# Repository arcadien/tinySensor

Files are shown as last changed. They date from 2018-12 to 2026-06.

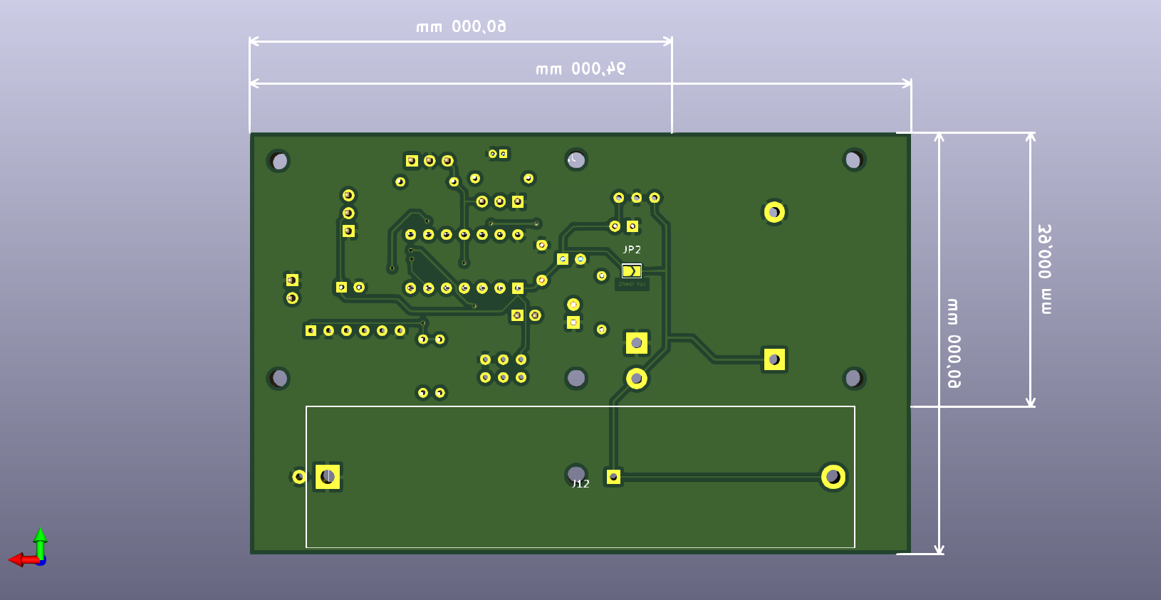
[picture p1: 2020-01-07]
doc/boardv2_copper.png

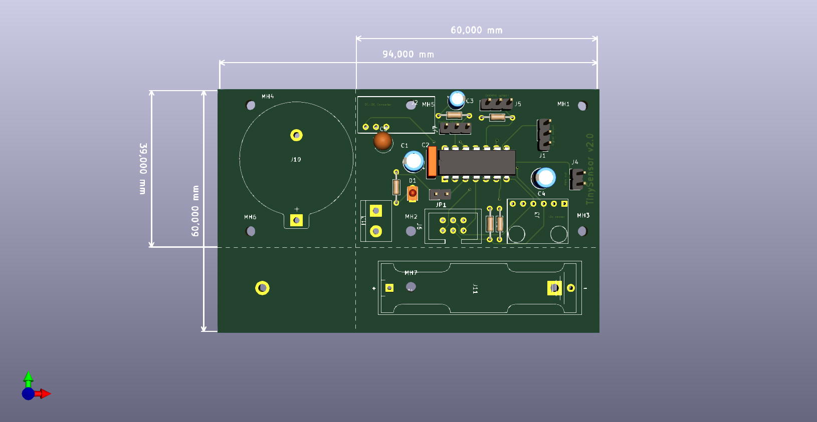
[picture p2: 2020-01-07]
doc/boardv2.png

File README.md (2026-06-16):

# TinySensor 



TinySensor aims to provide a customisable firmware and a hardware design for low-power environment sensors using wireless communication.

In the complete system, data is processed by a [Domoticz](https://domoticz.com/)/[RFlink](http://www.rflink.nl/blog2/) couple.
Data decoding is also tested using [RTL_433](https://github.com/merbanan/rtl_433) decoder.
Large part of the code, especially wireless encoders, are unit-tested.

## Supported MCUs
* ATTiny84a
* ATMega328p (ongoing)

## Supported sensors
* I2C sensors (eg. [Bosch BME/BMP280](https://www.bosch-sensortec.com/bst/products/all_products/bme280))
* Analog sensors (eg. [LM35](http://www.ti.com/lit/ds/symlink/lm35.pdf))
* OneWire sensors (eg. [Dallas DS18S20](https://datasheets.maximintegrated.com/en/ds/DS18S20.pdf))

## Wireless technology
* "one pin" emmiters. Tested with low-cost 433Mhz emmitters.

## Wireless protocol
* Oregon(c) for environment measurement transmission
* X10(c) for (optional) battery level transmission
* Lacrosse Technology for enviroment measurement transmission

## Used libraries
Various libraries are used here, and some where tweaked to remove any Arduino dependencies, making the whole firmware more compact:
* Sparkfun [BME280 sensor library](https://github.com/sparkfun/SparkFun_BME280_Arduino_Library) with all SPI related code removed
* [Tiny I2C](https://github.com/arcadien/tiny-i2c.git) of [David Johnson-Davies](https://github.com/technoblogy)
* [Unity test harness](http://www.throwtheswitch.org/unity) from Throw The Switch, for all testing code
* DS18B20 library of [Jacek Wieczorek](https://github.com/Jacajack/avr-ds18b20)

## Firmware builder
A web application wrapped in a Docker container allow to build the firmware in a sealed environment. NOTE: It is at his early stage!

## Useful documentation about low power AVR
* [AVR4013: picoPower Basics](http://www.microchip.com/downloads/en/AppNotes/doc8349.pdf)

## Development

TinySensor build environment now uses [PlatformIO](https://platformio.org/).

## Hardware options

TinySensor can use combination of sensors, the limit comes from amount of flash memory on the ATTiny.

### DS18B20

OneWire sensor, cheap and efficient.

### BMP/BME 280 environment sensor
The [BMP280](https://www.bosch-sensortec.com/products/environmental-sensors/pressure-sensors/pressure-sensors-bmp280-1.html) and the [BME280](https://www.bosch-sensortec.com/products/environmental-sensors/humidity-sensors-bme280/) share the same library, but the BME provide humidity sensing, and thus use more memory.

### Analog sensor

Analog sensor can be used for [LM35](https://www.ti.com/lit/ds/symlink/lm35.pdf) temperature sensor, or [LDR](https://en.wikipedia.org/wiki/Photoresistor).

### LM35 temperature sensor

#### Without negative temperature support
A 0v ground reference is needed.
Solder pads *2* and *3* of **J4**, (rear side) as well **JP3**. 

#### With negative temperature support
In the case of a *-CAZ* version, temperature below 0 can be measured. 
To allow this, two 1N914 diodes must be placed to put the sensor reference below 0v. This setup is documented in the LM35 datasheet.
On TinySensor board v2.1 and up, this can be implemented by:
* solding **D2** and **D3** diodes
*solding **R4** with a value of 18k
* solding **JP3** to bypass C3 capacitor
* solding pads *1* and *2* of **J4** (rear side) to set ground reference.

#### Notes about swing

You can add a filter capacitor *C3* to avoid swing if the wire is long. In this case, do not solder *JP3*.
See datasheet for details.

# LDR
Use the right value for **R4** (should match the used LDR) and solder **JP3** and, on **JP4**, middle and *3* pads. This way, there will be no RC filter (no cap because of **J3**) and Vss analog reference thanks of **JP4**.

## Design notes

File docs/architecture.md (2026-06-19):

# Architecture

_Last updated: 2026-06-19 — requirements: TECH-SENSOR-001_

## Component Diagram

```mermaid
graph TD
  main["main.cpp (loop)"] -->|Hal*| HAL
  main -->|Hal*| OregonV3
  main -->|Hal*| LacrosseWS7000
  main -->|Hal*| x10rf
  main -->|Hal*| BMx280
  main -->|Hal*| SoftSerial
  main -->|Hal*| Ds18b20["Ds18b20 (1-Wire wrapper)"]
  Ds18b20 -->|"1-Wire PA3"| ds18b20["ds18b20 (1-Wire driver library)"]
  main -->|"I2C 0x23"| BH1750["BH1750 (I2C light sensor)"]

  HAL["Hal (interface)"] --> Attiny84aHal["Attiny84aHal (AVR)"]
  HAL --> TestHal["TestHal_ (host/test)"]

  OregonV3 -->|RadioGoHigh/Low\nDelay512Us/1024Us| HAL
  LacrosseWS7000 -->|RadioGoHigh/Low\nDelay400Us| HAL
  x10rf -->|"RadioGoHigh/Low\nDelayX10PreambleHigh/Low\nDelayX10BitShort/Long\nDelayX10Gap"| HAL
  SoftSerial -->|SerialGoHigh/Low| HAL
  BMx280 -->|I2C via TinyI2C| HAL
  Ds18b20 -->|Delay1s| HAL
```

## Component Responsibilities

| Component | Responsibility | Requirement(s) |
|---|---|---|
| `Hal` | Pure-virtual interface isolating all hardware I/O | — |
| `Attiny84aHal` | ATtiny84a production implementation of Hal | — |
| `TestHal_` | Host-native stub; records HAL calls as char tokens in `Orders` vector | — |
| `OregonV3` | Encodes temperature/humidity/pressure into Oregon Scientific v3 frames | — |
| `LacrosseWS7000` | Encodes temperature/humidity/pressure/luminosity into Lacrosse WS7000 frames | — |
| `x10rf` | Encodes meter readings into X10 RF frames (battery voltage, analog sensors); routes all timing through Hal X10 delay methods | TECH-X10-001, TECH-X10-002 |
| `BMx280` | Abstracts BMP280/BME280 I2C sensor behind a common interface | — |
| `Ds18b20` | Wrapper class encapsulating DS18B20 1-Wire access; accepts `Hal*` at construction; exposes `Begin()`, `Convert()`, `Read()`; uses `hal->Delay1s()` between convert and read on AVR; stubs on non-AVR | TECH-SENSOR-001 |
| `SoftSerial` | Software UART for debug logging (optional, `USE_SERIAL_LOG`) | — |
| `ds18b20` | 1-Wire driver library on PA3; called only through `Ds18b20` wrapper | FUNC-SENSOR-002 |
| `BH1750` | I2C light sensor at 0x23; ONE_TIME_HIGH_RES_MODE; result in lux | FUNC-SENSOR-003 |
| `main.cpp` | Measurement loop: power on → read sensors → encode → transmit → hibernate | — |
| `AnalogFilter` | Accumulates ADC samples with configurable warm-up exclusion; returns integer floor mean | TECH-FILTER-001, TECH-FILTER-002 |
| `ConversionTools` | BCD-in-hex conversion utilities for 16-bit and 32-bit decimal values | TECH-CONVERT-001, TECH-CONVERT-002 |

## Dependency Injection Map

| Component | Receives | Via |
|---|---|-----|
| `OregonV3` | `Hal*` | constructor |
| `LacrosseWS7000` | `Hal*` | constructor |
| `x10rf` | `Hal*` | constructor |
| `BMx280` | `Hal*` | constructor |
| `Ds18b20` | `Hal*` | constructor |
| `SoftSerial` | `Hal*` | constructor |

All protocol encoders and sensor wrappers receive `Hal*` at construction. They must never access AVR registers directly.

## Build-time Configuration

Every physical board is a separate PlatformIO environment with its own `build_flags`. There is no runtime configuration. See `docs/environments.md` for the full table.

## Requirement → Component Traceability

| Requirement | Component(s) | Notes |
|---|---|---|
| FUNC-OREGON-001 | `OregonV3` | Zero bit HAL call sequence (H-D512-L-D1024-H-D512) |
| FUNC-OREGON-002 | `OregonV3` | One bit HAL call sequence (L-D512-H-D1024-L-D512) |
| FUNC-OREGON-003 | `OregonV3` | Byte serialisation: LSB nibble before MSB nibble |
| FUNC-OREGON-004 | `OregonV3` | Frame structure: 3-byte preamble + payload + 1-byte postamble |
| FUNC-OREGON-005 | `OregonV3` | Positive temperature encoding in bytes 4–5 |
| FUNC-OREGON-006 | `OregonV3` | Negative temperature sign flag in byte 5 |
| FUNC-OREGON-007 | `OregonV3` | Humidity encoding with swapped nibbles in byte 6 |
| FUNC-OREGON-008 | `OregonV3` | Pressure encoding with 795 hPa offset; weather prediction in byte 9 |
| FUNC-OREGON-009 | `OregonV3` | Channel 1–3 encoded as bitmask in byte 2; out-of-range ignored |
| FUNC-OREGON-010 | `OregonV3` | Rolling code stored in low nibble of byte 2 and high nibble of byte 3 |
| FUNC-OREGON-011 | `OregonV3` | Battery-low flag is bit 2 of byte 3 |
| FUNC-OREGON-012 | `OregonV3` | Device ID auto-selected by FinalizeMessage() based on messageStatus |
| FUNC-OREGON-013 | `OregonV3` | messageStatus bit-field (bit0=temp, bit1=humi, bit2=press) |
| FUNC-OREGON-014 | `OregonV3` | Full frame matches Oregon Scientific v3 reference decoding samples |
| FUNC-LACROSSE-001 | `LacrosseWS7000` | Preamble is exactly 10 consecutive zero bits |
| FUNC-LACROSSE-002 | `LacrosseWS7000` | Sensor-type nibble encoding: 0=temp, 1=T+H, 4=T+H+P, 5=lux, F=unknown |
| FUNC-LACROSSE-003 | `LacrosseWS7000` | Address (0–7) in bits 0–2; negative temperature sign in bit 3 of second nibble |
| FUNC-LACROSSE-004 | `LacrosseWS7000` | Temperature clamped ±99 °C; encoded as decimal/unit/dozen nibbles |
| FUNC-LACROSSE-005 | `LacrosseWS7000` | Humidity clamped to 99.9 %; encoded as decimal/unit/dozen nibbles |
| FUNC-LACROSSE-006 | `LacrosseWS7000` | Pressure clamped 850–1100 hPa, offset −200; encoded as four nibbles |
| FUNC-LACROSSE-007 | `LacrosseWS7000` | Luminosity encoded as 7 nibbles in type-5 (light sensor) frame |
| FUNC-LACROSSE-008 | `LacrosseWS7000` | Frame ends with XOR checksum nibble and running-sum nibble (init 5) |
| FUNC-LACROSSE-009 | `LacrosseWS7000` | Each nibble followed by mandatory trailing one-bit separator |
| FUNC-X10-001 | `x10rf` | RFXmeter 6-byte frame: address, partial complement, 24-bit value, packet-type nibble, nibble-sum parity |
| FUNC-X10-002 | `x10rf` | RFXsensor 4-byte frame: address+type bits, partial complement, value, packet-type status + nibble-sum parity |
| FUNC-X10-003 | `x10rf` | x10Switch 4-byte frame: house-code nibble lookup, bit-scattered unit code, full-byte complements |
| FUNC-X10-004 | `x10rf` | x10Security 6-byte frame: address, swapped-nibble complement, command + complement, id, XOR-fold parity |
| FUNC-X10-005 | `x10rf` | Transmission repeated rf_repeats times with 40 ms inter-repeat cooldown via DelayX10Gap (see TECH-X10-001) |
| FUNC-X10-006 | `main.cpp` | Battery voltage BCD-encoded and transmitted via RFXmeter; suppressed when lowBattery |
| FUNC-X10-007 | `main.cpp` | Analog sensor voltage BCD-encoded and transmitted via RFXmeter; suppressed when lowBattery |
| TECH-HAL-001 | `Hal` / `Attiny84aHal` / `TestHal_` | Encoders and wrappers take Hal* at construction; no direct AVR register access |
| TECH-HAL-002 | `TestHal_` | Orders vector char-token recording: H, L, D, P, A, S, W |
| TECH-HAL-003 | `Hal` | ComputeVccMv and ConvertAnalogValueToMv are non-virtual concrete methods on Hal base |
| TECH-HAL-004 | `Attiny84aHal` | Constructor power-reduction: disables Timer1, ADC, analog comparator; pull-ups unused pins; BOD-sleep disable |
| TECH-HAL-005 | `Attiny84aHal` / `TestHal_` | LedOn/LedOff toggle PORTB PB1 on AVR; toggle IsLedOn in TestHal_ |
| TECH-HAL-006 | `Attiny84aHal` / `TestHal_` | Init() calls TinyI2C.init() on AVR (USE_I2C); sets I2CIsConfigured in TestHal_ |
| TECH-FILTER-001 | `AnalogFilter` | Discards first `exclusion` values; accumulates up to `samples`; Get() returns integer floor mean |
| TECH-FILTER-002 | `AnalogFilter` | Push() after samples count reached is silently ignored; Get() returns mean of first samples values |
| TECH-CONVERT-001 | `ConversionTools` | dec16ToHex packs each decimal digit of uint16_t into one nibble (BCD-in-hex) |
| TECH-CONVERT-002 | `ConversionTools` | dec32ToHex packs each decimal digit of uint32_t into one nibble (BCD-in-hex) |
| TECH-SERIAL-001 | `SoftSerial` | Output-only UART at 9600 baud; bit period = (1 000 000 / 9600) − 25 µs; driven by SerialGoHigh/Low |
| TECH-SERIAL-002 | `main.cpp` | SoftSerial instantiated and SerialPrintInfo active only when USE_SERIAL_LOG defined; otherwise no-op |
| TECH-X10-001 | `Hal` / `Attiny84aHal` / `TestHal_` | Five new pure-virtual Hal methods: DelayX10PreambleHigh (8960 µs), DelayX10PreambleLow (4500 µs), DelayX10BitShort (560 µs), DelayX10BitLong (1120 µs), DelayX10Gap (40000 µs) |
| TECH-X10-002 | `x10rf` | x10rf replaces all file-static _delay_us() calls with the five new Hal timing methods; <util/delay.h> block removed |
| FUNC-BATTERY-001 | `Hal` / `main.cpp` | ComputeVccMv reads internal 1.1 V ADC ref; calibrated constant supplied as INTERNAL_1v1 build flag |
| FUNC-BATTERY-002 | `Hal` / `main.cpp` | batteryVoltageInMv = vccMv (BATTERY_IS_VCC) or ConvertAnalogValueToMv(GetRawBattery(), vccMv) |
| FUNC-BATTERY-003 | `main.cpp` | lowBattery flag gates Oregon SetBatteryLow and suppresses all RFXmeter transmissions |
| FUNC-SENSOR-001 | `BMx280` | Wraps BMP280/BME280 at I2C 0x76; Begin/GetTemperature/GetPressure/GetHumidity/Shutdown interface |
| FUNC-SENSOR-002 | `Ds18b20` | ds18b20convert + ds18b20read on PA3; raw / 16 = temperature in °C; accessed only through Ds18b20 wrapper |
| TECH-SENSOR-001 | `Ds18b20` | DS18B20 access encapsulated in Ds18b20 wrapper; main.cpp must not reference PORTA/DDRA/PINA or ds18b20 library functions directly |
| FUNC-SENSOR-003 | `main.cpp` (BH1750) / `LacrosseWS7000` | BH1750 at I2C 0x23 ONE_TIME_HIGH_RES_MODE; lux reported as two Lacrosse type-5 frames |
| FUNC-ANALOG-001 | `Hal` / `main.cpp` | GetRawAnalogSensor() reads PA0; ConvertAnalogValueToMv converts to mV using vccMv from FUNC-BATTERY-001 |
| CONF-BUILD-001 | `main.cpp` / `platformio.ini` | Exactly one of USE_OREGON or USE_LACROSSE per environment; violated at compile time otherwise |
| CONF-BUILD-002 | `main.cpp` / `include/config.h` | Sensor type flag (USE_BMP280/BME280/DS18B20/BH1750) selects included driver; USE_I2C auto-derived |
| CONF-BUILD-003 | `main.cpp` / `platformio.ini` | OREGON_CHANNEL (1–3) and OREGON_RCODE (≤ 0xA5) applied to OregonV3 in main() |
| CONF-BUILD-004 | `main.cpp` / `platformio.ini` | LACROSSE_ID enum value applied to LacrosseWS7000 in main() |
| CONF-BUILD-005 | `Hal` / `platformio.ini` | INTERNAL_1v1 (mV) chip-calibrated constant consumed by Hal::ComputeVccMv() |
| CONF-BUILD-006 | `main.cpp` / `include/config.h` | SLEEP_TIME_IN_SECONDS passed to Hal::Hibernate(); default 32 s from config.h |
| CONF-BUILD-007 | `main.cpp` / `include/config.h` | LOW_BATTERY_VOLTAGE compared against batteryVoltageInMv; default 2000 mV from config.h |
| CONF-BUILD-008 | `main.cpp` / `platformio.ini` | BATTERY_VOLTAGE_X10_ID passed as address to x10rf::RFXmeter() for battery reporting |
| CONF-BUILD-009 | `main.cpp` / `platformio.ini` | ANALOG1_X10_ID optionally enables PA0 analog transmission via x10rf::RFXmeter() |
| CONF-BUILD-010 | `main.cpp` / `platformio.ini` | BATTERY_IS_VCC skips GetRawBattery(); batteryVoltageInMv = vccMv directly |
| CONF-BUILD-011 | `platformio.ini` | USE_CHARGE_PUMP is an informational flag only; no firmware branch depends on it |
| PLAT-POWER-001 | `Attiny84aHal` | Hibernate loops SLEEP_MODE_PWR_DOWN for ceil(s/8) WDT periods; minimum 1 period |
| PLAT-POWER-002 | `Attiny84aHal` / `main.cpp` | PA2 (SENSOR_VCC) driven high before first sensor read; driven low after last transmission |
| PLAT-POWER-003 | `Attiny84aHal` | PRR bits for USI/Timer0/Timer1/ADC set in sleep(); GPIO reconfigured as inputs with pull-ups; all restored on wake |
| PLAT-POWER-004 | `main.cpp` | TRANSMIT_WITH_LED macro wraps every Send(): LedOn() before, LedOff() + Delay30ms() after |
| PLAT-POWER-005 | `Attiny84aHal` / `platformio.ini` | ATtiny84a at F_CPU = 1 000 000 L; all HAL delay methods calibrated to this frequency |

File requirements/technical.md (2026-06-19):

# Technical Requirements

<!-- Requirements are added here during Phase 2 of the RBD workflow. -->
<!-- Format: req(ID): title -->

### TECH-HAL-001
**Title:** All encoders and sensor wrappers receive Hal* at construction and never access AVR registers directly
**Status:** validated
**Dependencies:** —
**Description:** Every protocol encoder (`OregonV3`, `LacrosseWS7000`, `x10rf`, `SoftSerial`) and sensor wrapper (`BMx280`) must accept a `Hal*` parameter at construction time and must call only `Hal` virtual methods for all hardware I/O. Direct access to AVR registers (`PORTA`, `PORTB`, `ADCSRA`, etc.) is forbidden outside `Attiny84aHal`.

---

### TECH-HAL-002
**Title:** TestHal_ records each HAL call as a single-character token in the Orders vector
**Status:** validated
**Dependencies:** TECH-HAL-001
**Description:** `TestHal_` appends one character per call to its `Orders` vector: `H`=`RadioGoHigh`, `L`=`RadioGoLow`, `D`=`Delay512Us`, `P`=`Delay1024Us`, `A`=`Delay400Us`, `S`=`SerialGoHigh`, `W`=`SerialGoLow`. Protocol tests verify correctness by asserting against expected `Orders` sequences.

---

### TECH-HAL-003
**Title:** ComputeVccMv and ConvertAnalogValueToMv are non-virtual concrete methods on the Hal base class
**Status:** validated
**Dependencies:** —
**Description:** `Hal::ComputeVccMv(uint16_t known11refValue)` and `Hal::ConvertAnalogValueToMv(uint16_t adcReading, uint16_t vccInMv)` are implemented directly on `Hal` and are not overridden by any subclass. Both `Attiny84aHal` and `TestHal_` inherit them unchanged.

---

### TECH-HAL-004
**Title:** Attiny84aHal constructor disables Timer1, ADC, and analog comparator; pull-ups all unused pins; disables brownout detection during sleep
**Status:** validated
**Dependencies:** —
**Description:** `Attiny84aHal()` calls `UseLessPowerAsPossible()`, which sets `DDRA`/`DDRB` to 0, applies pull-ups via `PORTA`/`PORTB`, disables the analog comparator (`ACSR|=ACD`), disables Timer1 (`PRR|=PRTIM1`), clears `ADCSRA` and disables the ADC (`PRR|=PRADC`), and deactivates brownout detection during sleep (`MCUCR BODS/BODSE` sequence).

---

### TECH-HAL-005
**Title:** LedOn and LedOff toggle PORTB PB1 on AVR hardware and toggle IsLedOn in TestHal_
**Status:** validated
**Dependencies:** —
**Description:** `Attiny84aHal::LedOn()` sets bit `PB1` in `PORTB`; `LedOff()` clears it. In `TestHal_`, `LedOn()` sets `IsLedOn = true` and `LedOff()` sets `IsLedOn = false`. The `test_led` suite verifies this boolean toggle.

---

### TECH-HAL-006
**Title:** Hal::Init initialises the I2C bus when USE_I2C is defined, and sets I2CIsConfigured in TestHal_
**Status:** validated
**Dependencies:** —
**Description:** `Attiny84aHal::Init()` calls `TinyI2C.init()` when compiled with `USE_I2C`; it is a no-op otherwise. `TestHal_::Init()` sets `I2CIsConfigured = true`. The `test_busses` suite verifies that `Init()` results in `I2CIsConfigured` being `true`.

---

### TECH-FILTER-001
**Title:** AnalogFilter discards the first `exclusion` values then accumulates up to `samples` values and returns their integer floor mean
**Status:** validated
**Dependencies:** —
**Description:** `AnalogFilter::Push(value)` decrements `exclusion` and discards the value until `exclusion` reaches zero; thereafter it accumulates values into `accumulator` up to `samples` count. `Get()` returns `accumulator / actualValuesCount` (integer division), or 0 if no values were accumulated.

---

### TECH-FILTER-002
**Title:** Values pushed to AnalogFilter after the samples count is reached are silently ignored
**Status:** validated
**Dependencies:** TECH-FILTER-001
**Description:** Once `actualValuesCount` equals `samples`, subsequent `Push()` calls do nothing: the accumulator is not modified and `actualValuesCount` is not incremented. `Get()` continues to return the mean of the first `samples` values only.

---

### TECH-CONVERT-001
**Title:** dec16ToHex returns the BCD hex representation of a uint16_t with each decimal digit in one nibble
**Status:** validated
**Dependencies:** —
**Description:** `ConversionTools::dec16ToHex(n)` packs each decimal digit of `n` into one nibble of the returned `uint16_t` (e.g. 4200 → `0x4200`). Inputs above 9999 cause the most-significant nibble to overflow silently; no error is raised.

---

### TECH-CONVERT-002
**Title:** dec32ToHex returns the 32-bit BCD hex representation of a uint32_t with each decimal digit in one nibble
**Status:** validated
**Dependencies:** —
**Description:** `ConversionTools::dec32ToHex(n)` packs each decimal digit of `n` into one nibble of the returned `uint32_t` (e.g. 1234567 → `0x01234567`). Inputs above 99,999,999 cause the most-significant nibble to overflow silently; no error is raised.

---

### TECH-SERIAL-001
**Title:** SoftSerial transmits output-only UART at 9600 baud using SerialGoHigh/SerialGoLow HAL calls
**Status:** validated
**Dependencies:** TECH-HAL-001
**Description:** `SoftSerial` accepts a `Hal*` at construction and drives UART output exclusively via `SerialGoHigh()` and `SerialGoLow()`. Each bit period is `(1 000 000 / 9600) − 25` µs, as defined by `BIT_PERIOD` in `lib/softSerial/SoftSerial.cpp:6`. No receive path is implemented.

---

### TECH-SERIAL-002
**Title:** Debug logging via SoftSerial is compiled only when USE_SERIAL_LOG is defined
**Status:** validated
**Dependencies:** TECH-SERIAL-001
**Description:** When `USE_SERIAL_LOG` is defined, `src/main.cpp` includes `SoftSerial.h`, instantiates `SoftSerial swSerial(&hal)`, and implements `SerialPrintInfo(name, value, unit)` using it. When `USE_SERIAL_LOG` is absent, `SerialPrintInfo` is a no-op inline function and `SoftSerial` is not instantiated.

---

### TECH-X10-001
**Title:** Hal must expose five timing methods for X10 RF signal intervals
**Status:** validated
**Dependencies:** TECH-HAL-001
**Description:** The `Hal` interface must declare five new pure-virtual methods for X10 RF timing: `DelayX10PreambleHigh()` (8960 µs), `DelayX10PreambleLow()` (4500 µs), `DelayX10BitShort()` (560 µs), `DelayX10BitLong()` (1120 µs), and `DelayX10Gap()` (40000 µs). `Attiny84aHal` must implement each with the corresponding `_delay_us()` call calibrated to `F_CPU = 1 000 000`. `TestHal_` must implement each by appending a distinct single-character token to `Orders`.

---

### TECH-X10-002
**Title:** x10rf must call only Hal timing methods for all delays; direct _delay_us() calls are forbidden
**Status:** validated
**Dependencies:** TECH-X10-001
**Description:** `x10rf::SendCommand()` and `x10rf::SendX10RfBit()` must replace all calls to the file-static `x10_*` delay functions with direct calls to the corresponding `Hal` methods (`DelayX10PreambleHigh()`, `DelayX10PreambleLow()`, `DelayX10BitShort()`, `DelayX10BitLong()`, `DelayX10Gap()`). The `#if defined(AVR)` block defining those static functions and including `<util/delay.h>` must be removed entirely from `lib/x10/x10rf.cpp`.

---

### TECH-SENSOR-001
**Title:** DS18B20 access encapsulated in a Ds18b20 wrapper class; main.cpp must not reference AVR registers or ds18b20 library functions directly
**Status:** validated
**Dependencies:** TECH-HAL-001, FUNC-SENSOR-002
**Description:** A `Ds18b20` wrapper class (header `include/Ds18b20.h`) must encapsulate all 1-Wire DS18B20 interactions following the same pattern as `BMx280`. On AVR, `Ds18b20` must accept a `Hal*` at construction and expose `Begin()`, `Convert()`, `Read()` (returning `int16_t` temperature in °C as integer), and use `hal->Delay1s()` between `ds18b20convert` and `ds18b20read` internally. On non-AVR targets all methods must be stubs returning 0. `main.cpp` must not call `ds18b20convert()`, `ds18b20read()`, or reference `PORTA`, `DDRA`, or `PINA` in any `USE_DS18B20` code path; all such calls are delegated exclusively to `Ds18b20`.

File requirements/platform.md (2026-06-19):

# Platform Requirements

<!-- Requirements are added here during Phase 2 of the RBD workflow. -->
<!-- Format: req(ID): title -->

### PLAT-POWER-001
**Title:** Hibernate loops SLEEP_MODE_PWR_DOWN for ceil(s/8) WDT periods
**Status:** validated
**Dependencies:** TECH-HAL-004
**derives_from:** [TECH-HAL-004](technical.md#tech-hal-004)
**Description:** `Attiny84aHal::Hibernate(s)` delegates to `sleep(s)`, which computes `n = s >> 3` (minimum 1) and enters `SLEEP_MODE_PWR_DOWN` via the 8-second hardware watchdog timer exactly `n` times. A request of fewer than 8 seconds still produces one sleep period.

---

### PLAT-POWER-002
**Title:** Sensor power rail PA2 driven high before first read and low after last transmission
**Status:** validated
**Dependencies:** FUNC-SENSOR-001
**derives_from:** [FUNC-SENSOR-001](functional.md#func-sensor-001)
**Description:** In each iteration of the measurement loop, `hal.PowerOnSensors()` drives PA2 (`SENSOR_VCC`) high before any sensor read; `hal.PowerOffSensors()` drives PA2 low immediately after the last transmission and before `Hibernate()`. No sensor read or transmission occurs outside this power window.

---

### PLAT-POWER-003
**Title:** Hibernate disables USI/Timer0/Timer1/ADC and reconfigures all GPIO as inputs with pull-ups; restores all state on wake
**Status:** validated
**Dependencies:** PLAT-POWER-001, TECH-HAL-004
**derives_from:** [TECH-HAL-004](technical.md#tech-hal-004)
**Description:** Before entering the first sleep period, `sleep()` sets PRR bits for PRUSI, PRTIM0, PRTIM1, and PRADC; sets DDRA and DDRB to 0; and applies pull-ups to unused pins. After the last sleep period, all five registers (PRR, DDRA, DDRB, PORTA, PORTB) are restored to their pre-sleep values.

---

### PLAT-POWER-004
**Title:** Each Send() call is flanked by LedOn() before and LedOff() + Delay30ms() after via TRANSMIT_WITH_LED
**Status:** validated
**Dependencies:** TECH-HAL-005
**derives_from:** [TECH-HAL-005](technical.md#tech-hal-005)
**Description:** The `TRANSMIT_WITH_LED(code)` macro defined in `src/main.cpp` expands to: call `hal.LedOn()`, execute `code` (the `Send()` call), call `hal.LedOff()`, then call `hal.Delay30ms()`. Every protocol `Send()` invocation in the measurement loop must be wrapped in this macro.

---

### PLAT-POWER-005
**Title:** Target MCU is ATtiny84a at 1 MHz; all Attiny84aHal delay methods are calibrated to F_CPU = 1 000 000
**Status:** validated
**Dependencies:** TECH-HAL-001
**derives_from:** [TECH-HAL-001](technical.md#tech-hal-001)
**Description:** All physical PlatformIO environments inherit `[env:avr_base]`, which sets `board_build.f_cpu = 1000000L` and `board_build.mcu = attiny84a`. All `Attiny84aHal` delay methods (`Delay512Us`, `Delay1024Us`, `Delay400Us`, `Delay30ms`) are calibrated exclusively for this 1 MHz clock frequency.

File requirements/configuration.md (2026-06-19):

# Configuration Requirements

<!-- Requirements are added here during Phase 2 of the RBD workflow. -->
<!-- Format: req(ID): title -->

### CONF-BUILD-001
**Title:** Enforce exclusive protocol selection at compile time
**Status:** validated
**Dependencies:** —
**Description:** Exactly one of `USE_OREGON` or `USE_LACROSSE` must be defined per build environment. Defining neither causes a compile error because no protocol encoder is included; defining both causes a compile error due to conflicting encoder instantiation in `main.cpp`.

### CONF-BUILD-002
**Title:** Select sensor type exclusively via build flags
**Status:** validated
**Dependencies:** —
**Description:** Exactly one of `USE_BMP280`, `USE_BME280`, `USE_DS18B20`, or `USE_BH1750` must be defined per build environment to select the active sensor. When any I2C sensor flag (`USE_BMP280`, `USE_BME280`, or `USE_BH1750`) is present and `USE_I2C` is not explicitly defined, `config.h` auto-derives `USE_I2C`.

### CONF-BUILD-003
**Title:** Set Oregon channel and rolling code per environment
**Status:** validated
**Dependencies:** CONF-BUILD-001
**Description:** When `USE_OREGON` is defined, `OREGON_CHANNEL` must be set to an integer in the range 1–3 and `OREGON_RCODE` must be set to a value no greater than `0xA5`. Both are passed directly to `OregonV3::SetChannel()` and `OregonV3::SetRollingCode()` in `main()`.

### CONF-BUILD-004
**Title:** Set Lacrosse device address per environment
**Status:** validated
**Dependencies:** CONF-BUILD-001
**Description:** When `USE_LACROSSE` is defined, `LACROSSE_ID` must be set to a valid `LacrosseWS7000::Address` enum value. It is passed directly to `LacrosseWS7000::SetAddress()` in `main()`.

### CONF-BUILD-005
**Title:** Supply individually calibrated internal 1.1 V reference per board
**Status:** validated
**Dependencies:** FUNC-BATTERY-001
**Description:** `INTERNAL_1v1` must be defined in millivolts for each physical ATtiny84a board via `build_flags`. Its value represents the actual measured voltage of that chip's internal 1.1 V ADC reference, which varies chip to chip, and is consumed by `Hal::ComputeVccMv()`.

### CONF-BUILD-006
**Title:** Configure hibernate duration via SLEEP_TIME_IN_SECONDS
**Status:** validated
**Dependencies:** —
**Description:** `SLEEP_TIME_IN_SECONDS` sets the duration in seconds that the firmware hibernates between measurement cycles. When not defined, `config.h` defaults it to 32 seconds.

### CONF-BUILD-007
**Title:** Configure low-battery threshold via LOW_BATTERY_VOLTAGE
**Status:** validated
**Dependencies:** FUNC-BATTERY-003
**Description:** `LOW_BATTERY_VOLTAGE` sets the battery voltage threshold in millivolts below which the `lowBattery` flag is raised. When not defined, `config.h` defaults it to 2000 mV.

### CONF-BUILD-008
**Title:** Assign a unique X10 meter address for battery voltage reporting
**Status:** validated
**Dependencies:** FUNC-X10-006
**Description:** `BATTERY_VOLTAGE_X10_ID` must be defined and must be unique across all boards transmitting to the same receiver. It is passed as the address argument to `x10rf::RFXmeter()` when reporting battery voltage.

### CONF-BUILD-009
**Title:** Optionally assign an X10 meter address for auxiliary analog reporting
**Status:** validated
**Dependencies:** FUNC-X10-007, FUNC-ANALOG-001
**Description:** When `ANALOG1_X10_ID` is defined, the firmware reads PA0 and transmits the converted millivolt value via `x10rf::RFXmeter()` using that address. When undefined, no analog channel transmission occurs. The address must be unique across all boards reporting to the same receiver.

### CONF-BUILD-010
**Title:** Signal direct VCC battery measurement via BATTERY_IS_VCC
**Status:** validated
**Dependencies:** FUNC-BATTERY-002
**Description:** When `BATTERY_IS_VCC` is defined, `batteryVoltageInMv` is set directly to `vccMv` and `GetRawBattery()` is not called. This applies to boards where no external resistor divider is present on PA1 and VCC equals battery voltage.

### CONF-BUILD-011
**Title:** Document charge-pump sensor rail via USE_CHARGE_PUMP
**Status:** validated
**Dependencies:** —
**Description:** `USE_CHARGE_PUMP` is an informational build flag documenting that the sensor VCC rail on a given board is boosted via a charge pump. No firmware code branches on this flag; it exists solely for build-system documentation purposes.

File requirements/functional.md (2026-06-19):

# Functional Requirements

<!-- Requirements are added here during Phase 2 of the RBD workflow. -->
<!-- Format: req(ID): title -->

### FUNC-OREGON-001
**Title:** Zero bit encoded as H-D512-L-D1024-H-D512 HAL call sequence
**Status:** validated
**Dependencies:** —
**Description:** When `SendZero()` is called, `OregonV3` emits exactly six HAL calls in order: `RadioGoHigh`, `Delay512Us`, `RadioGoLow`, `Delay1024Us`, `RadioGoHigh`, `Delay512Us`. This sequence is the sole representation of a zero bit on the radio channel.

### FUNC-OREGON-002
**Title:** One bit encoded as L-D512-H-D1024-L-D512 HAL call sequence
**Status:** validated
**Dependencies:** —
**Description:** When `SendOne()` is called, `OregonV3` emits exactly six HAL calls in order: `RadioGoLow`, `Delay512Us`, `RadioGoHigh`, `Delay1024Us`, `RadioGoLow`, `Delay512Us`. This sequence is the sole representation of a one bit on the radio channel.

### FUNC-OREGON-003
**Title:** Data bytes transmitted LSB-nibble first then MSB-nibble
**Status:** validated
**Dependencies:** FUNC-OREGON-001, FUNC-OREGON-002
**Description:** `SendData()` iterates over each byte and transmits its low nibble (bits 0–3) before its high nibble (bits 4–7), each bit sent via `SendZero()` or `SendOne()`. This nibble order applies to every byte in the message, preamble, and postamble.

### FUNC-OREGON-004
**Title:** Frame begins with 24 one-bits preamble and ends with 2-zero-bit postamble byte
**Status:** validated
**Dependencies:** FUNC-OREGON-001, FUNC-OREGON-002
**Description:** Every `Send()` call first transmits three `0xFF` preamble bytes (24 one-bits total via `SendData`), then the 11-byte message payload, then one `0x00` postamble byte (8 zero-bits, equivalent to two zero nibbles).

### FUNC-OREGON-005
**Title:** Positive temperature encoded as decimal, unit, and dozen nibbles in bytes 4–5
**Status:** validated
**Dependencies:** —
**Description:** `SetTemperature()` with a non-negative value encodes the tenths digit into the high nibble of byte 4, the units digit into the low nibble of byte 4, and the dozens digit into the high nibble of byte 5. The low nibble of byte 5 is reserved for the sign flag.

### FUNC-OREGON-006
**Title:** Negative temperature sets sign bit in byte 5 and encodes absolute value
**Status:** validated
**Dependencies:** FUNC-OREGON-005
**Description:** When the temperature argument to `SetTemperature()` is negative, `OregonV3` sets bit 3 of byte 5 (`0x08`) as a negative sign flag, then encodes the absolute value using the same decimal/unit/dozen layout as for positive temperatures.

### FUNC-OREGON-007
**Title:** Humidity encoded in byte 6 with units and dozens nibbles swapped
**Status:** validated
**Dependencies:** —
**Description:** `SetHumidity()` accepts a value in the range 0–99 and stores the units digit in the high nibble of byte 6 and the dozens digit in the low nibble of byte 6, reversing the conventional tens-before-units order.

### FUNC-OREGON-008
**Title:** Pressure encoded with 795 hPa offset in bytes 7–8; weather prediction byte at byte 9
**Status:** validated
**Dependencies:** —
**Description:** `SetPressure()` subtracts 795 from the hPa value and stores the result across bytes 7 and 8. Byte 9 holds a weather-prediction code: 0x30 (rain, <1000 hPa), 0x20 (cloudy, <1010), 0x60 (partly cloudy, <1025), or 0xC0 (sunny, ≥1025).

### FUNC-OREGON-009
**Title:** Channel (1–3) encoded as 1-bit mask in high nibble of byte 2; out-of-range silently ignored
**Status:** validated
**Dependencies:** —
**Description:** `SetChannel()` accepts values 1, 2, or 3 and sets bit `(4 + channel - 1)` of byte 2, producing 0x10, 0x20, or 0x40 respectively. Any value outside the range 1–3 is silently ignored and the message byte is left unchanged.

### FUNC-OREGON-010
**Title:** Rolling code (≤ 0xA5) stored across low nibble of byte 2 and high nibble of byte 3
**Status:** validated
**Dependencies:** —
**Description:** `SetRollingCode()` writes the high nibble of the rolling code byte into the low nibble of byte 2 and the low nibble of the rolling code byte into the high nibble of byte 3. Values greater than `0xA5` are accepted without validation.

### FUNC-OREGON-011
**Title:** Battery-low flag is bit 2 of byte 3; cleared when battery is OK
**Status:** validated
**Dependencies:** —
**Description:** `SetBatteryLow(true)` sets bit 2 of byte 3 (`message[3] |= 0x04`). `SetBatteryLow(false)` clears bit 2 (`message[3] &= 0xFB`). All other bits of byte 3 are unaffected.

### FUNC-OREGON-012
**Title:** Device ID auto-selected at Send() based on which fields are populated
**Status:** validated
**Dependencies:** FUNC-OREGON-001, FUNC-OREGON-002
**Description:** `FinalizeMessage()` writes the Oregon Scientific device ID into bytes 0–1 based on `messageStatus`: temperature-only sets `0xEC40` (THN132N); temperature and humidity sets `0x1D20` (THGN123N); temperature, humidity, and pressure sets `0x5A5D` (BTHR918). The checksum is computed and appended accordingly.

### FUNC-OREGON-013
**Title:** messageStatus bit-field tracks which fields are set (bit 0=temp, bit 1=humi, bit 2=press)
**Status:** validated
**Dependencies:** FUNC-OREGON-001, FUNC-OREGON-002
**Description:** The private `messageStatus` byte is initialised to 0. `SetTemperature()` sets bit 0, `SetHumidity()` sets bit 1, and `SetPressure()` sets bit 2. The field is readable via `GetMessageStatus()` and governs device-ID selection in `FinalizeMessage()`.

### FUNC-OREGON-014
**Title:** Full frame byte sequence matches Oregon Scientific v3 reference decoding samples
**Status:** validated
**Dependencies:** FUNC-OREGON-001, FUNC-OREGON-002, FUNC-OREGON-003, FUNC-OREGON-004, FUNC-OREGON-005, FUNC-OREGON-006, FUNC-OREGON-007, FUNC-OREGON-008, FUNC-OREGON-009, FUNC-OREGON-010, FUNC-OREGON-011, FUNC-OREGON-012, FUNC-OREGON-013
**Description:** The 11-byte payload produced by `FinalizeMessage()` for known channel, rolling code, battery, temperature, humidity, and pressure inputs must match the reference hex strings from the Oregon Scientific v3 protocol document (e.g., `5A5D423448088209603054`, `1D20485448088200390000`, `1D2016B0091073002C0000`).

### FUNC-LACROSSE-001
**Title:** Preamble is exactly 10 consecutive zero bits
**Status:** validated
**Dependencies:** —
**Description:** `SendPreamble()` transmits exactly 10 zero bits by calling `SendZero()` ten times. No other bits precede the preamble. The preamble is always followed by a single one-bit start marker emitted by `Send()` before the first nibble.

### FUNC-LACROSSE-002
**Title:** Sensor-type nibble encodes available data combination; unknown combination emits 0xF
**Status:** validated
**Dependencies:** —
**Description:** `SendType()` maps the `availableData` bitmask to a type nibble: temperature-only (0x01) → 0x0, temperature and humidity (0x03) → 0x1, temperature, humidity, and pressure (0x07) → 0x4, luminosity-only (0x08) → 0x5. Any other combination emits 0xF.

### FUNC-LACROSSE-003
**Title:** Address (0–7) in bits 0–2 of second nibble; negative temperature sign in bit 3
**Status:** validated
**Dependencies:** —
**Description:** `SendAddressAndTemperatureSign()` encodes the 3-bit sensor address in bits 0–2. If temperature is available and negative, bit 3 is set to 1. The resulting nibble is sent via `SendNibble()`.

### FUNC-LACROSSE-004
**Title:** Temperature clamped to ±99 °C and encoded as three nibbles: decimal, unit, dozen
**Status:** validated
**Dependencies:** —
**Description:** `SetTemperature()` clamps the input to [−99, +99] °C. `SendTemperature()` then transmits three nibbles in order: tenths digit, units digit, dozens digit. The sign is communicated separately via FUNC-LACROSSE-003.

### FUNC-LACROSSE-005
**Title:** Humidity clamped to 99.9 % maximum and encoded as three nibbles: decimal, unit, dozen
**Status:** validated
**Dependencies:** —
**Description:** `SetHumidity()` clamps any value ≥ 100 % to 99.9 %. `SendHumidity()` transmits three nibbles in order: tenths digit, units digit, dozens digit.

### FUNC-LACROSSE-006
**Title:** Pressure clamped to 850–1100 hPa, offset by −200, encoded as four nibbles: units, dozens, hundreds, decimal
**Status:** validated
**Dependencies:** —
**Description:** `SetPressure()` clamps the input to [850, 1100] hPa then subtracts 200. `SendPressure()` transmits four nibbles in order: units digit, dozens digit, hundreds digit, tenths digit of the offset value.

### FUNC-LACROSSE-007
**Title:** Luminosity value encoded as 7 nibbles in a type-5 (light sensor) frame
**Status:** validated
**Dependencies:** —
**Description:** `SendLuminosity()` transmits the units, dozens, and hundreds nibbles of the lux value followed by four zero nibbles, giving a fixed 7-nibble payload. The type nibble for luminosity frames is 0x5 (see FUNC-LACROSSE-002).

### FUNC-LACROSSE-008
**Title:** Frame ends with XOR checksum nibble followed by running-sum nibble initialised to 5
**Status:** validated
**Dependencies:** FUNC-LACROSSE-001, FUNC-LACROSSE-002, FUNC-LACROSSE-003, FUNC-LACROSSE-004, FUNC-LACROSSE-005, FUNC-LACROSSE-006, FUNC-LACROSSE-007
**Description:** `Send()` maintains a running XOR (`checkXor`, init 0) and a running sum (`checkSum`, init 5) over every transmitted nibble. After all data nibbles, `checkXor` is masked to 4 bits, added into `checkSum` (also masked to 4 bits), and both are transmitted as the final two nibbles.

### FUNC-LACROSSE-009
**Title:** Each nibble is followed by a mandatory trailing one-bit separator
**Status:** validated
**Dependencies:** —
**Description:** `SendNibble()` always calls `SendOne()` after transmitting its four data bits. This trailing one-bit separator is unconditional and applies to every nibble in the frame, including type, address, data, and checksum nibbles.

### FUNC-X10-001
**Title:** RFXmeter builds a 6-byte frame with address, partial complement, 24-bit value, packet-type nibble, and nibble-sum parity
**Status:** validated
**Dependencies:** —
**Description:** `RFXmeter()` fills a 6-byte buffer: byte[0]=address, byte[1]=(upper nibble of ~address)+(lower nibble of address), bytes[2–4]=24-bit value (clamped to 0 on overflow), byte[5] upper nibble=packet type, byte[5] lower nibble=bitwise NOT of sum of all byte nibble-pairs. The buffer is transmitted via `SendCommand`.

### FUNC-X10-002
**Title:** RFXsensor builds a 4-byte frame with address-type encoding, value, packet-type status, and nibble-sum parity
**Status:** validated
**Dependencies:** —
**Description:** `RFXsensor()` fills a 4-byte buffer: byte[0]=(address<<2)|type_bits (t=0,v=2,a=1,m=3), byte[1]=(upper nibble of ~byte[0])+(lower nibble of byte[0]), byte[2]=value, byte[3] upper nibble=packet-type status byte, byte[3] lower nibble=bitwise NOT of nibble sum of bytes[0–2] and byte[3] upper nibble. The buffer is transmitted via `SendCommand`.

### FUNC-X10-003
**Title:** x10Switch builds a 4-byte frame with house-code nibble lookup, bit-scattered unit encoding, and full-byte complements
**Status:** validated
**Dependencies:** —
**Description:** `x10Switch()` maps house-code characters 'a'–'p' to a 4-bit lookup table value placed in byte[0] upper nibble. Unit code bits are scattered across byte[0] bit 2 and byte[2] bits 3, 4, 6. Byte[1]=~byte[0] and byte[3]=~byte[2]. The 4-byte buffer is transmitted via `SendCommand`.

### FUNC-X10-004
**Title:** x10Security builds a 6-byte frame with XOR-fold parity reduced to a single bit
**Status:** validated
**Dependencies:** —
**Description:** `x10Security()` fills a 6-byte buffer: byte[0]=address, byte[1]=(lower nibble of ~byte[0])+(upper nibble of byte[0]), byte[2]=command, byte[3]=~command, byte[4]=id. Byte[5] is the XOR of all six bytes (using byte[5] bit 7 only), folded by successive XOR-halvings to a single bit. The buffer is transmitted via `SendCommand`.

### FUNC-X10-005
**Title:** Each transmission is repeated rf_repeats times with a 40 ms inter-repeat cooldown on AVR
**Status:** validated
**Dependencies:** —
**Description:** `SendCommand()` loops `_rf_repeats` times. Each iteration sends the preamble burst, all frame bits MSB-first, and a trailing stop bit, then calls `x10_cooldown_gap()` (40 000 µs delay on AVR, no-op on host). `LedOn`/`LedOff` bracket the full repeated sequence.

### FUNC-X10-006
**Title:** Battery voltage in mV is BCD-encoded and transmitted via RFXmeter when battery is not low
**Status:** validated
**Dependencies:** FUNC-X10-001, FUNC-BATTERY-001, FUNC-BATTERY-002
**Description:** When `BATTERY_VOLTAGE_X10_ID` is defined and `lowBattery` is false, `main()` reads VCC in mV, converts it to BCD via `ConversionTools::dec16ToHex`, and calls `x10encoder.RFXmeter(BATTERY_VOLTAGE_X10_ID, 0x00, value)`. The transmission is suppressed entirely when `lowBattery` is true.

### FUNC-X10-007
**Title:** Auxiliary analog sensor voltage in mV is BCD-encoded and transmitted via RFXmeter when battery is not low
**Status:** validated
**Dependencies:** FUNC-X10-001, FUNC-ANALOG-001
**Description:** When `ANALOG1_X10_ID` is defined and `lowBattery` is false, `main()` reads the raw analog sensor value, converts it to mV via `hal.ConvertAnalogValueToMv`, BCD-encodes via `ConversionTools::dec16ToHex`, and calls `x10encoder.RFXmeter(ANALOG1_X10_ID, 0x00, value)`. The transmission is suppressed when `lowBattery` is true.

### FUNC-BATTERY-001
**Title:** VCC computed from ATtiny84a internal 1.1 V reference
**Status:** validated
**Dependencies:** —
**Description:** `Hal::ComputeVccMv(known11refValue)` reads the raw ADC value of the internal 1.1 V reference via `GetRawInternal11Ref()` and returns `(uint16_t)(known11refValue * 1024.0 / rawAnalog11ref)`. The calibrated reference value is supplied as `INTERNAL_1v1` at build time.

### FUNC-BATTERY-002
**Title:** Battery voltage derived from VCC directly or resistor-divider on PA1
**Status:** validated
**Dependencies:** FUNC-BATTERY-001
**Description:** When `BATTERY_IS_VCC` is defined, `batteryVoltageInMv` equals `vccMv`. Otherwise, `main()` reads PA1 via `hal.GetRawBattery()` and calls `hal.ConvertAnalogValueToMv(rawBattery, vccMv)` to obtain the battery voltage in millivolts from the external resistor divider.

### FUNC-BATTERY-003
**Title:** Low-battery flag suppresses X10 meter transmissions and sets Oregon battery-low bit
**Status:** validated
**Dependencies:** FUNC-BATTERY-002, FUNC-OREGON-011, FUNC-X10-006, FUNC-X10-007
**Description:** When `batteryVoltageInMv < LOW_BATTERY_VOLTAGE`, `main()` sets `lowBattery = true`. Oregon frames receive `SetBatteryLow(true)`. All X10 RFXmeter transmissions guarded by `!lowBattery` (battery voltage and analog sensor) are suppressed entirely.

### FUNC-SENSOR-001
**Title:** BMx280 wraps BMP280 and BME280 behind a common interface at I2C address 0x76
**Status:** validated
**Dependencies:** —
**Description:** The `BMx280` class initialises the sensor at I2C address 0x76 and exposes `Begin()`, `GetTemperature()` (°C), `GetPressure()` (Pa), `GetHumidity()` (%), and `Shutdown()` (sleep mode). On non-AVR targets the methods are stubs returning 0.

### FUNC-SENSOR-002
**Title:** DS18B20 temperature read on 1-Wire PA3; raw value divided by 16 gives degrees Celsius
**Status:** validated
**Dependencies:** —
**Description:** When `USE_DS18B20` is defined on AVR, `main()` calls `ds18b20convert()` on PORTA bit 3, waits 1 s, then calls `ds18b20read()`. On `DS18B20_ERROR_OK`, the raw 16-bit fixed-point value is right-shifted by dividing by 16 to obtain temperature in °C as an integer.

### FUNC-SENSOR-003
**Title:** BH1750 light sensor read in ONE_TIME_HIGH_RES_MODE and reported as a Lacrosse type-5 luminosity frame transmitted twice
**Status:** validated
**Dependencies:** FUNC-LACROSSE-007
**Description:** When `USE_BH1750` is defined and `lowBattery` is false, `main()` initialises a `BH1750` at I2C address 0x23 in `ONE_TIME_HIGH_RES_MODE`, waits 150 ms, reads the lux value, sets it on a `LacrosseWS7000` encoder, and calls `Send()` twice to maximise reception reliability.

### FUNC-ANALOG-001
**Title:** Auxiliary analog input on PA0 read and converted to millivolts
**Status:** validated
**Dependencies:** FUNC-BATTERY-001
**Description:** When `ANALOG1_X10_ID` is defined and `lowBattery` is false, `main()` calls `hal.GetRawAnalogSensor()` (PA0 ADC reading) and converts it to millivolts via `hal.ConvertAnalogValueToMv(rawAdc, vccMv)`, where `vccMv` was computed by `ComputeVccMv(INTERNAL_1v1)`.

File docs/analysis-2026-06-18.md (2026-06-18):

# Architecture Analysis — 2026-06-18

_Generated by rbd:arch-analyst as input for requirements reverse-engineering._

## Summary

- **Components identified:** 10 (`main.cpp`, `Hal`, `Attiny84aHal`, `TestHal_`, `OregonV3`, `LacrosseWS7000` + `NumericalValueSplitter`, `x10rf`, `SoftSerial`, `AnalogFilter`, `BMx280`, `ConversionTools`)
- **Requirement files status:** all six `requirements/*.md` files are empty templates — zero validated requirements exist
- **Candidate requirements identified:** 68 across 8 domains
- **Architectural violations:** 4 (see section below)

---

## Global Component Diagram

```mermaid
graph LR
  subgraph "src/"
    main["main.cpp (measurement loop)"]
  end

  subgraph "lib/hal/"
    Hal["Hal (pure-virtual interface)"]
    Attiny84aHal["Attiny84aHal (AVR production)"]
    TestHal_["TestHal_ (host/test stub)"]
  end

  subgraph "lib/oregon/"
    OregonV3["OregonV3 (Oregon Sci. v3 encoder)"]
  end

  subgraph "lib/LacrosseWS7000/"
    LacrosseWS7000["LacrosseWS7000 (Lacrosse WS7000 encoder)"]
    NumericalValueSplitter["NumericalValueSplitter (float decomposition)"]
  end

  subgraph "lib/x10/"
    x10rf["x10rf (X10 RF encoder)"]
  end

  subgraph "lib/softSerial/"
    SoftSerial["SoftSerial (debug UART)"]
  end

  subgraph "lib/utils/"
    AnalogFilter["AnalogFilter (sliding-window mean)"]
    ConversionTools["ConversionTools (dec-to-BCD hex)"]
  end

  subgraph "include/"
    BMx280["BMx280 (BMP280/BME280 wrapper)"]
    config["config.h (compile-time defaults)"]
  end

  main -->|"Hal* DI"| Hal
  main -->|"Hal* DI"| OregonV3
  main -->|"Hal* DI"| LacrosseWS7000
  main -->|"Hal* DI"| x10rf
  main -->|"Hal* DI"| BMx280
  main -->|"Hal* DI"| SoftSerial
  main -->|uses| ConversionTools
  main -->|includes| config
 
  Attiny84aHal -->|implements| Hal
  TestHal_ -->|implements| Hal
 
  OregonV3 -->|"RadioGoHigh/Low, Delay512Us/1024Us"| Hal
  LacrosseWS7000 -->|"RadioGoHigh/Low, Delay400Us"| Hal
  LacrosseWS7000 -->|uses| NumericalValueSplitter
  x10rf -->|"RadioGoHigh/Low, LedOn/Off"| Hal
  SoftSerial -->|"SerialGoHigh/Low"| Hal
  BMx280 -->|"I2C via TinyI2C"| Hal

  Attiny84aHal -.->|"undeclared dep"| AnalogFilter
```

---

## Architectural Violations (must resolve before formalising requirements)

| # | Component | Violation | Location |
|---|---|---|---|
| V1 | `x10rf` | Bypasses HAL for all timing on AVR — direct `_delay_us` calls for 9 ms preamble, 4.5 ms gap, 560 µs/1120 µs bit periods, 40 ms cooldown | `lib/x10/x10rf.cpp:44-67` |
| V2 | `Attiny84aHal` | Undeclared dependency on `AnalogFilter` (include at line 2, used in `AdcRead`) | `lib/hal/Attiny84aHal.cpp:2` |
| V3 | `main.cpp` | `BH1750` sensor component absent from `docs/architecture.md` | `src/main.cpp:24-25, 161-174` |
| V4 | `main.cpp` | `ds18b20` 1-Wire component absent from `docs/architecture.md` | `src/main.cpp:29-32, 119-130` |

---

## Requirements Reverse-Engineering Map

### FUNC-OREGON — Oregon Scientific v3 encoding

| Proposed ID | Short description | Source | Tested? |
|---|---|---|---|
| FUNC-OREGON-001 | Zero bit → H-D512-L-D1024-H-D512 HAL sequence | `Oregon_v3.cpp:97-104` | Yes — `Expect_good_hardware_orders_for_zero` |
| FUNC-OREGON-002 | One bit → L-D512-H-D1024-L-D512 HAL sequence | `Oregon_v3.cpp:120-127` | Yes — `Expect_good_hardware_orders_for_one` |
| FUNC-OREGON-003 | Data bytes sent LSB-nibble first then MSB-nibble | `Oregon_v3.cpp:82-87` | Yes — `Expect_nibbles_to_be_sent_lsb_first` |
| FUNC-OREGON-004 | Frame begins with 24 one-bits (3×0xFF preamble) and ends with 2 zero-nibble postamble | `Oregon_v3.cpp:200-213` | Yes — `Expect_messages_to_have_preamble_and_postamble` |
| FUNC-OREGON-005 | Positive temperature encoded as decimal/unit/dozen in nibbles 8-11 | `Oregon_v3.cpp:138-165` | Yes — `Expect_right_positive_temperature_encoding` |
| FUNC-OREGON-006 | Negative temperature: bit 3 of nibble 9 set, absolute value encoded | `Oregon_v3.cpp:141-143` | Yes — `Expect_right_negative_temperature_encoding` |
| FUNC-OREGON-007 | Humidity (0-99 %) in nibbles 12-13 with tens/units swapped | `Oregon_v3.cpp:129-136` | Yes — `Expect_right_humidity_encoding` |
| FUNC-OREGON-008 | Pressure (850-1099 hPa, offset -795) in nibbles 14-17; weather-prediction byte at nibble 18 | `Oregon_v3.cpp:35-57` | Yes — `Expect_right_pressure_encoding` |
| FUNC-OREGON-009 | Channel (1-3) in nibble 4 as `1 << (channel-1)`; out-of-range ignored | `Oregon_v3.cpp:106-110` | Yes — `Expect_right_channel_encoding` |
| FUNC-OREGON-010 | Rolling code (≤ 0xA5) encoded in nibbles 5-6 | `Oregon_v3.cpp:115-118` | Yes — `Expect_right_rolling_code_encoding` |
| FUNC-OREGON-011 | Battery-low flag is bit 2 of nibble 7 | `Oregon_v3.cpp:27-33` | Yes — `Expect_right_battery_ok_encoding`, `Expect_right_low_battery_encoding` |
| FUNC-OREGON-012 | Device ID auto-selected at Send(): THN132N (0xEC40) temp-only, THGN123N (0x1D20) temp+humi, BTHR918 (0x5A5D) all | `Oregon_v3.cpp:167-199` | Yes — three sensor-type tests |
| FUNC-OREGON-013 | `messageStatus` bit-field tracks which fields are set (bit0=temp, bit1=humi, bit2=press) | `Oregon_v3.h:91` | Yes — `Expect_*_set_to_change_message_status` |
| FUNC-OREGON-014 | Full frame matches Oregon Scientific reference decoding samples | `Oregon_v3.cpp` | Yes — `Expect_sample_message_to_be_well_encoded`, `Expect_implementation_follows_samples_1/2` |

### FUNC-LACROSSE — Lacrosse WS7000 encoding

| Proposed ID | Short description | Source | Tested? |
|---|---|---|---|
| FUNC-LACROSSE-001 | Preamble is exactly 10 consecutive zero bits | `LacrosseWS7000.cpp:75-79` | Yes — `Expect_preamble_is_10_times_0` |
| FUNC-LACROSSE-002 | Type nibble: 0=temp, 1=T+H, 4=T+H+P, 5=lux, F=error | `LacrosseWS7000.cpp:81-93` | Yes — `Expect_good_sensor_type_emission` |
| FUNC-LACROSSE-003 | Address (0-7) in bits 0-2 of second nibble; temperature sign in bit 3 | `LacrosseWS7000.cpp:95-102` | Yes — `Expect_good_sensor_address_emission` |
| FUNC-LACROSSE-004 | Temperature clamped ±99 °C; encoded as decimal/unit/dozen nibbles | `LacrosseWS7000.cpp:42-49, 104-111` | Yes — `Expect_good_temperature_emission` |
| FUNC-LACROSSE-005 | Humidity clamped 0-99.9 %; encoded as decimal/unit/dozen nibbles | `LacrosseWS7000.cpp:20-25, 131-138` | Yes — `Expect_good_humidity_emission` |
| FUNC-LACROSSE-006 | Pressure clamped 850-1100 hPa, offset -200; four nibbles: units/dozens/hundreds/decimal | `LacrosseWS7000.cpp:27-35, 140-148` | Yes — `Expect_good_pressure_emission` |
| FUNC-LACROSSE-007 | Luminosity (lux) as 7 nibbles in type-5 (light sensor) frame | `LacrosseWS7000.cpp:113-129` | Yes — `Expect_encoding_of_simple_luminosity_message` |
| FUNC-LACROSSE-008 | Frame ends with XOR checksum nibble and running-sum nibble (init 5) over all transmitted nibbles | `LacrosseWS7000.cpp:158-196` | Yes — all frame-level tests |
| FUNC-LACROSSE-009 | Each nibble followed by mandatory trailing one-bit separator | `LacrosseWS7000.cpp:67-73` | Yes — implicit in all frame tests |

### FUNC-X10 — X10 RF encoding

| Proposed ID | Short description | Source | Tested? |
|---|---|---|---|
| FUNC-X10-001 | `RFXmeter`: 6-byte frame; address, complement, 24-bit BCD value, type nibble, parity nibble | `x10rf.cpp:121-215` | Yes — `Expect_x10_meter_right_encoding` |
| FUNC-X10-002 | `RFXsensor`: 4-byte frame; address, type, value, parity | `x10rf.cpp:217-259` | Yes — `Expect_x10_sensor_right_encoding` |
| FUNC-X10-003 | `x10Switch`: 4-byte frame with house-code nibble lookup, unit bit encoding, complement bytes | `x10rf.cpp:261-293` | Yes — `Expect_x10_switch_right_encoding` |
| FUNC-X10-004 | `x10Security`: 6-byte frame with XOR-fold parity over all bytes | `x10rf.cpp:295-322` | Yes — `Expect_x10_security_right_parity` |
| FUNC-X10-005 | Each transmission repeated `rf_repeats` times with 40 ms inter-repeat cooldown | `x10rf.cpp:69-90` | No — cooldown AVR-only, no-op in tests |
| FUNC-X10-006 | Battery voltage (mV, BCD via `dec16ToHex`) transmitted via `RFXmeter(BATTERY_VOLTAGE_X10_ID)`; suppressed when `lowBattery` | `main.cpp:132-146` | No |
| FUNC-X10-007 | Auxiliary analog voltage (mV, BCD) via `RFXmeter(ANALOG1_X10_ID)`; suppressed when `lowBattery` | `main.cpp:149-159` | No |

### FUNC-SENSOR — Sensor reading

| Proposed ID | Short description | Source | Tested? |
|---|---|---|---|
| FUNC-SENSOR-001 | `BMx280` wraps BMP280/BME280 behind Begin/GetTemperature/GetPressure/GetHumidity/Shutdown at I2C 0x76 | `include/BMx280.h` | No — AVR-only |
| FUNC-SENSOR-002 | DS18B20 read via `ds18b20convert` + `ds18b20read` on PA3; raw/16 = °C | `main.cpp:119-130` | No |
| FUNC-SENSOR-003 | BH1750 read in ONE_TIME_HIGH_RES_MODE at I2C 0x23; reported as Lacrosse type-5 luminosity frame | `main.cpp:161-174` | No |

### FUNC-BATTERY — Battery measurement

| Proposed ID | Short description | Source | Tested? |
|---|---|---|---|
| FUNC-BATTERY-001 | VCC derived from 1.1 V internal ref: `vccMv = INTERNAL_1v1 * (1024 / rawInternal11Ref)` | `Hal.h:32-37` | Yes — `test_power` |
| FUNC-BATTERY-002 | Battery voltage = VCC directly (`BATTERY_IS_VCC`) or PA1 resistor divider via `ConvertAnalogValueToMv` | `main.cpp:133-139`, `Hal.h:39-42` | Yes — `test_power` |
| FUNC-BATTERY-003 | When battery < `LOW_BATTERY_VOLTAGE`: `lowBattery=true`, Oregon frames get `SetBatteryLow(true)`, X10 meter frames suppressed | `main.cpp:140-146` | Partial — bit encoding tested; suppression not |

### FUNC-ANALOG — Analog sensor

| Proposed ID | Short description | Source | Tested? |
|---|---|---|---|
| FUNC-ANALOG-001 | PA0 analog value read via `GetRawAnalogSensor()` and converted to mV using `ConvertAnalogValueToMv(rawAdc, vccMv)` | `main.cpp:151-157`, `Attiny84aHal.cpp:212-214` | No |

### TECH-HAL — HAL abstraction

| Proposed ID | Short description | Source | Tested? |
|---|---|---|---|
| TECH-HAL-001 | All encoders and sensor wrappers receive `Hal*` at construction; never access AVR registers directly | `Hal.h`, all encoder constructors | Implicit — all unit tests inject `&TestHal` |
| TECH-HAL-002 | `TestHal_` records calls as char tokens in `Orders`: H/L=Radio, D=Delay512Us, P=Delay1024Us, A=Delay400Us, S/W=Serial | `TestHal.h:41-53` | Yes — all protocol suites |
| TECH-HAL-003 | `Hal::ComputeVccMv` and `Hal::ConvertAnalogValueToMv` are non-virtual concrete methods shared by both HAL implementations | `Hal.h:32-42` | Yes — `test_power` |
| TECH-HAL-004 | `Attiny84aHal` constructor disables Timer1, ADC, analog comparator; sets pull-ups on unused pins; disables BOD during sleep | `Attiny84aHal.cpp:35-63` | No |
| TECH-HAL-005 | LED state: `LedOn`/`LedOff` toggle PORTB PB1 on AVR; toggle `IsLedOn` boolean in TestHal | `Attiny84aHal.cpp:141-147`, `TestHal.h:55-56` | Yes — `test_led` |
| TECH-HAL-006 | `Hal::Init()` initialises I2C bus (TinyI2C.init() on AVR; sets `I2CIsConfigured=true` in TestHal) | `Attiny84aHal.h:52-56`, `TestHal.h:69` | Yes — `test_busses` |

### TECH-SERIAL — SoftSerial debug output

| Proposed ID | Short description | Source | Tested? |
|---|---|---|---|
| TECH-SERIAL-001 | `SoftSerial` 9600-baud output-only UART using `SerialGoHigh/Low` with bit period `(1000000/9600) - 25` µs | `SoftSerial.cpp:6` | No |
| TECH-SERIAL-002 | Debug logging compiled only when `USE_SERIAL_LOG` defined; otherwise `SerialPrintInfo` is no-op inline | `main.cpp:69-83` | No |

### TECH-FILTER — Analog filtering

| Proposed ID | Short description | Source | Tested? |
|---|---|---|---|
| TECH-FILTER-001 | `AnalogFilter` discards first `exclusion` values pushed, accumulates up to `samples`, returns integer mean | `AnalogFilter.cpp` | Yes — `test_analogFiltering` (6 cases) |
| TECH-FILTER-002 | `AnalogFilter` silently ignores values pushed after `samples` count is reached | `AnalogFilter.cpp:4-11` | Yes — `Expect_filter_to_ignore_supernumerary_values` |

### TECH-CONVERT — Numerical conversion

| Proposed ID | Short description | Source | Tested? |
|---|---|---|---|
| TECH-CONVERT-001 | `dec16ToHex`: decimal integer → BCD hex (e.g. 4200 → 0x4200); max 9999, overflow on higher values | `conversionTools.cpp:5-22` | Yes — `Test_dec16ToHex` |
| TECH-CONVERT-002 | `dec32ToHex`: decimal integer → 32-bit BCD hex; max 99 999 999, overflow on higher values | `conversionTools.cpp:24-42` | Yes — `Test_dec32ToHex` |

### CONF-BUILD — Build-time configuration

| Proposed ID | Short description | Source | Tested? |
|---|---|---|---|
| CONF-BUILD-001 | Exactly one of `USE_OREGON` or `USE_LACROSSE` must be defined per environment | `main.cpp:36-40`, `platformio.ini` | No |
| CONF-BUILD-002 | Sensor type selected via `USE_BMP280`, `USE_BME280`, `USE_DS18B20`, or `USE_BH1750`; `USE_I2C` auto-derived | `main.cpp:23-34`, `config.h:30-33` | No |
| CONF-BUILD-003 | Oregon channel (1-3) and rolling code (≤ 0xA5) set via `OREGON_CHANNEL` and `OREGON_RCODE` | `main.cpp:96-98`, `platformio.ini` S_02/S_04 | No |
| CONF-BUILD-004 | Lacrosse address set via `LACROSSE_ID` as `LacrosseWS7000::Address` enum value | `main.cpp:94-95`, `platformio.ini` S_03/robot/devmodule/SOLAR_TEST | No |
| CONF-BUILD-005 | `INTERNAL_1v1` must be individually calibrated per board (ATtiny84a chip-to-chip variation) | `platformio.ini` all AVR envs, `Hal.h:32-36` | No |
| CONF-BUILD-006 | `SLEEP_TIME_IN_SECONDS` sets hibernate interval; default 32 s | `config.h:22-24` | No |
| CONF-BUILD-007 | `LOW_BATTERY_VOLTAGE` (mV) set per environment to match battery chemistry; default 2000 mV | `config.h:26-28` | No |
| CONF-BUILD-008 | `BATTERY_VOLTAGE_X10_ID` assigns board-unique X10 meter address for battery voltage reporting | `main.cpp:55`, `platformio.ini` | No |
| CONF-BUILD-009 | `ANALOG1_X10_ID` optionally assigns board-unique X10 meter address for auxiliary analog reporting | `main.cpp:149`, `platformio.ini` SOLAR_TEST | No |
| CONF-BUILD-010 | `BATTERY_IS_VCC` signals VCC used directly as battery voltage (no resistor divider) | `main.cpp:134-135`, `platformio.ini` devmodule | No |
| CONF-BUILD-011 | `USE_CHARGE_PUMP` documents charge-pump sensor VCC rail (informational flag, not branched on in code) | `platformio.ini` S_02/S_03 | No |

### PLAT-POWER — Power management

| Proposed ID | Short description | Source | Tested? |
|---|---|---|---|
| PLAT-POWER-001 | MCU hibernates in `SLEEP_MODE_PWR_DOWN` driven by 8 s WDT; `Hibernate(s)` loops `s/8` WDT periods | `Attiny84aHal.cpp:72-113, 221-223` | No |
| PLAT-POWER-002 | Sensor power rail (PA2) asserted before measurement, de-asserted after all transmissions | `Attiny84aHal.cpp:133-138`, `main.cpp:102, 201` | No |
| PLAT-POWER-003 | During sleep: all pins become inputs with pull-ups; PRR bits for USI/Timer0/Timer1/ADC set; state restored on wake | `Attiny84aHal.cpp:83-113` | No |
| PLAT-POWER-004 | Each frame transmission flanked by `LedOn` before and `LedOff + Delay30ms` after (`TRANSMIT_WITH_LED` macro) | `main.cpp:61-67` | Partial — `test_led` tests LedOn/Off in isolation |
| PLAT-POWER-005 | Target MCU is ATtiny84a at 1 MHz; all HAL delay methods calibrated to this clock frequency | `platformio.ini:board_build.f_cpu=1000000L`, `Attiny84aHal.cpp` | No |

---

## Key Observations for Next Session

1. **68 candidate requirements** — none yet committed to `requirements/*.md`.
2. **Richest tested domains:** FUNC-OREGON (14 req, all tested), FUNC-LACROSSE (9 req, most tested), TECH-FILTER (2, tested), TECH-CONVERT (2, tested). Start there.
3. **Domains with zero test coverage:** FUNC-SENSOR, TECH-SERIAL, CONF-BUILD, most of PLAT-POWER. Needs req + tests before any code changes.
4. **4 architectural violations (V1-V4 above) should be addressed as TECH requirements** before new code is written. V1 (`x10rf` bypasses HAL) is the highest-priority because it contradicts the declared DI contract.
5. **Suggested dispatch order for requirement-analyst agents:**
   - Batch 1 (parallel): FUNC-OREGON, FUNC-LACROSSE (well-defined, well-tested)
   - Batch 2 (parallel): FUNC-X10, TECH-HAL, TECH-FILTER, TECH-CONVERT
   - Batch 3 (parallel): FUNC-BATTERY, FUNC-SENSOR, FUNC-ANALOG, TECH-SERIAL
   - Batch 4 (parallel): CONF-BUILD, PLAT-POWER
   - After all req committed: update `docs/architecture.md` to resolve V1-V4
6. **Commit format reminder:** `req(FUNC-OREGON-001): <title>` per requirement; `arch(FUNC-OREGON-001): <description>` for architecture updates.

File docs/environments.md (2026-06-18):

# PlatformIO environments

Each physical prototype board has `S_XX` written on its PCB. That label is the PlatformIO environment name. Every board gets its own environment because the ATtiny84a's internal 1.1 V reference (`INTERNAL_1v1`) varies chip-to-chip and must be calibrated individually — this is the only reason two otherwise identical boards need separate environments.

## How to calibrate `INTERNAL_1v1` for a new board

1. Power the board from a known stable voltage (e.g. bench supply or fresh alkaline).
2. Measure VCC accurately with a multimeter.
3. Flash any build and read the `Vbatt` value logged over serial (or from Domoticz).
4. Adjust `INTERNAL_1v1` until the reported value matches the measured VCC.
5. Reflash and verify.

## Physical boards

| Env | Protocol | Sensor | Battery | Notes |
|-----|---|---|---|---|
| `S_02` | Oregon v3, channel 1, rolling code `0x20` | BMP280 (temp + pressure) | 2× AA via charge pump | Prototype rev 2 |
| `S_03` | Lacrosse WS7000, address THREE | BMP280 (temp + pressure) | 2× AA via charge pump | Prototype rev 3 |
| `S_04` | Oregon v3, channel 1, rolling code `0x04` | BME280 (temp + humidity + pressure) | 2× AA | Prototype rev 4 |
| `S_05` | Oregon v3, channel 2, mode 2 | BME280 (temp + humidity + pressure) | 18650 Li-ion | Prototype rev 5 — older HW design, higher `INTERNAL_1v1=1343` reflects this chip |

## Special environments

| Env | Purpose |
|-----|---|
| `robot` | A robot device reworked to share the TinySensor PCB interface. Lacrosse WS7000 address THREE, BME280. |
| `devmodule` | Bench development board. `BATTERY_IS_VCC` — no battery divider, reports VCC directly. Lacrosse WS7000 address ONE, BME280. |
| `SOLAR_TEST` | CI simulation target via `simavr`. Lacrosse WS7000 address TWO, BME280 + BH1750 light sensor. Not a physical board — used to run on-device tests in the AVR simulator. |

## Battery voltage thresholds

`LOW_BATTERY_VOLTAGE` is set per environment to match the chemistry:

| Chemistry | Typical threshold |
|---|---|
| 2× AA alkaline (via charge pump) | 2200 mV |
| 2× AA alkaline (direct) | 2200 mV |
| 18650 Li-ion | 3400 mV |
| USB / bench (`BATTERY_IS_VCC`) | 3300 mV (informational) |

When the measured battery voltage falls below the threshold, the X10 battery meter frame is suppressed and `SetBatteryLow(true)` is sent in the Oregon frame.

## Adding a new board

1. Copy an existing `[env:S_XX]` block in `platformio.ini`.
2. Choose the protocol (`USE_OREGON` / `USE_LACROSSE`) and sensor (`USE_BMP280` / `USE_BME280` / `USE_BH1750` / `USE_DS18B20`).
3. Set `BATTERY_VOLTAGE_X10_ID` to a unique integer not used by any other board.
4. Set `INTERNAL_1v1=1100` as a starting value, then calibrate as above.
5. Assign the next `S_XX` label, write it on the PCB.

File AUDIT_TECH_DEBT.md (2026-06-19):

# Audit de dette technique — TinySensor

**Projet** : [arcadien/tinySensor](https://github.com/arcadien/tinySensor) — firmware AVR bas-consommation pour capteurs d'environnement sans fil (ATtiny84a, 433 MHz, protocoles Oregon v3 / Lacrosse WS7000 / X10).

**Auditeur** : Claude (modèle opus 4.7) — revue statique

**Date** : 19 avril 2026 — mise à jour 19 juin 2026 (voir §1bis)

**Périmètre** : ensemble du dépôt au commit `aa53a83` (branche `master`) — code firmware (`src/`, `lib/`, `include/`), tests (`test/`), projet Atmel Studio legacy (`TinySensor/`), outillage (`scripts/`, `shared/`), web builder (`web/`), hardware (`hardware/`), CI (`.github/workflows/`), Docker/devcontainer.

---

## 1. Synthèse exécutive

TinySensor est un projet firmware embarqué mature sur le plan fonctionnel (protocoles radio testés, HAL propre, tests unitaires natifs avec Unity, portage PlatformIO). Le code "cœur" (`lib/oregon`, `lib/LacrosseWS7000`, `lib/x10`, HAL) est propre, bien abstrait, testé. La dette se concentre dans trois zones qui pèsent sur la maintenabilité et le risque opérationnel :

D'abord, **un secret Coveralls est committé en clair** dans `.coveralls.yml` — il doit être révoqué immédiatement. Ensuite, **la CI ne compile aucun firmware AVR** (seul l'environnement natif est testé), donc un refactor peut casser silencieusement les builds de production `S_02`..`S_05`. Enfin, **un second arbre source** (`TinySensor/`, projet Atmel Studio legacy) duplique le code firmware et contient des binaires de build versionnés ; il est une source de divergence certaine et gonfle l'historique git.

Au-delà de ces trois points, la configuration per-device vit sous forme de blocs presque identiques dans `platformio.ini` (7 environnements avec copier-coller), les dépendances tirent toutes vers des forks personnels non épinglés, l'image Docker `php:7.4-apache` est EOL (novembre 2022), et plusieurs scripts d'outillage contiennent des chemins absolus spécifiques à l'auteur. L'ensemble est traitable en ~3 sprints d'un développeur à temps partiel, avec les gains de risque concentrés sur les deux premières semaines.

**Chiffres clés** : 3 779 lignes de code+tests sur ~20 fichiers. 8 suites de tests Unity natives. 1 workflow GitHub Actions (build + test native uniquement). 6 envs PlatformIO pour cibles physiques distinctes. 1 secret exposé. 2 dépendances critiques EOL.

---

## 1bis. Mises à jour de l'audit

Cette section suit l'évolution de la dette au fil des corrections apportées. Chaque entrée indique l'item résolu, la date, le(s) fichier(s) touché(s) et l'impact sur le score global.

### 2026-04-19 — Workflow GitHub Actions refondé

Fichier modifié : `.github/workflows/main.yml`

Trois items du top-20 traités en une seule PR :

- **T1 (36) — CI compile maintenant toutes les cibles AVR**. Le workflow a été scindé en deux jobs : `test-native` (inchangé) et `build-avr` avec matrice `[S_02, S_03, S_04, S_05, robot, devmodule, SOLAR_TEST]`. `fail-fast: false` pour isoler les pannes par env. → **Résolu**.
- **D2 (30) — Actions et Python mis à jour**. `checkout@v4`, `cache@v4`, `setup-python@v5`, Python `3.12` (remplace 3.9 EOL). Clé de cache désormais invalidée sur `hashFiles('platformio.ini')`. → **Résolu**.
- **I4 (20) — Artefacts firmware publiés**. Chaque build AVR upload `firmware.hex` + `firmware.elf` via `actions/upload-artifact@v4`, rétention 30 j. Addresse la partie "artefact téléchargeable" d'I4 ; la partie "release automation sur tag" reste à faire. → **Partiellement résolu**.

Également : déclenchement étendu aux pull requests (auparavant : `on: push` seul), et cache configuré avec fallback via `restore-keys`.

Impact global : **score cumulé réduit de 86 points** (36 + 30 + 20). Top-20 recomposé au §4.

### 2026-04-19 — `.gitignore` nettoyé et patrons d'artefacts ajoutés

Fichier modifié : `.gitignore`

- **I7 (20)** — Ligne 1 buggée `Debug/ Release/` (un seul pattern littéral avec espace) supprimée. Fichier réorganisé en blocs commentés. Ajout des patrons `*.o`, `*.d`, `*.hex`, `*.eep`, `*.lss`, `*.map`, `*.srec` (`*.elf` était déjà là). Préservation des fins de ligne CRLF. → **Résolu**.
- **I1 (25)** — Audit-revisité. `git ls-files TinySensor/Debug/` retourne vide : **aucun artefact n'était réellement tracké** (les `.o`/`.hex`/`.elf` sur disque proviennent d'une compilation locale Atmel Studio non committée). Le `git rm --cached` prévu par le plan est un no-op. Le nouveau `.gitignore` empêche toute régression : `git check-ignore` confirme que chaque fichier de `TinySensor/Debug/` match la règle `Debug/`. → **Résolu (par prévention ; l'audit initial surestimait l'item).**

Impact cumulé 2026-04-19 (toutes entrées confondues) : **131 points** (86 + 25 + 20).

### 2026-06-16 — Revue MAGI + nettoyage CI/outillage (PR #24)

Branche : `fix/magi-review-findings` — revue indépendante par trois agents MAGI (Gaspard, Melchior, Balthazar) ayant voté REJECT 2/3 sur des bugs firmware, suivie d'une session de corrections.

**Nouveaux bugs firmware identifiés par MAGI (non présents dans l'audit initial) :**

- **M1 — `PRR &= ~_BV(PRTIM1/PRADC)` logique inversée dans `UseLessPowerAsPossible()`** (`lib/hal/Attiny84aHal.cpp`). Dans le registre PRR, mettre un bit à 1 éteint le périphérique ; `&= ~` l'allumait (Timer1 et ADC restaient actifs en permanence). Corrigé en `|=`. Score rétroactif : (3+3)×5 = **30**. → **Résolu**.
- **M2 — `SetChannel()` sans validation de bornes** (`lib/oregon/Oregon_v3.cpp`). Channel > 3 décalait des bits dans les nibbles de l'ID capteur, corrompant silencieusement `message[2]`. Guard ajouté. Score rétroactif : (3+3)×5 = **30**. → **Résolu**.
- **M3 — `message[]` variable globale de fichier, non membre de classe** (`lib/oregon/Oregon_v3.cpp`). Singleton accidentel : deux instances `OregonV3` auraient partagé le même buffer. Déplacé en membre privé. Score rétroactif : (2+2)×4 = **16**. → **Résolu**.

**Items de l'audit résolus dans cette PR :**

- **C4 (20) — Dead-code `if (int(count) != count)` dans `OregonV3::Sum`**. Héritage d'une implémentation internet où `count` était `float` ; avec `uint8_t`, la branche est toujours fausse. Supprimée. → **Résolu**.
- **C7 (18) + C10 (15) — Duplication massive `platformio.ini`**. Introduction de `[env:avr_base]` + `extends` ; suppression du `USE_BMP280=1` en double dans `env:S_03`. → **Résolu**.
- **D9 (25) — Pas de Dependabot**. Fichier `.github/dependabot.yml` ajouté : mises à jour hebdomadaires pour `github-actions`, mensuelles pour `docker` et `pip`. → **Résolu**.
- **I4 (12) — Release automation sur tag** (partie restante). Job `release` ajouté au workflow : se déclenche sur `v*`, télécharge tous les artefacts firmware et publie une GitHub Release avec notes auto-générées. → **Résolu (complètement)**.
- **D8/Doc7 (10) — Badge Travis mort**. Remplacé par le badge GitHub Actions dans `README.md`. → **Résolu**.

Impact 2026-06-16 : **176 points** résolus (M1:30 + M2:30 + M3:16 + C4:20 + C7:18 + C10:15 + D9:25 + I4:12 + D8:10).

Impact cumulé toutes dates : **307 points** (131 + 176).

### 2026-06-18 — Révocation du token Coveralls + suppression de `web/` + requalification A1

- **C1 (35) — Token Coveralls révoqué et sorti du repo**. Le token `K1UMmvKnmugffPWriB48kR274KXcAuvuK` présent dans `.coveralls.yml` a été révoqué côté coveralls.io et remplacé par un secret GitHub Actions `COVERALLS_REPO_TOKEN`. → **Résolu**.
- **D1 (36) + A4 (15) + D6 (12) — `web/` supprimé**. Décision : le firmware builder web n'a jamais été finalisé ni déployé. Suppression des deux fichiers (`web/build.php`, `web/index.html`). Élimine d'un coup l'image Docker PHP 7.4 EOL, la vulnérabilité `shell_exec`, et jQuery 1.12.4. → **Résolu (D1, A4, D6)**.
- **A1 — Requalifié (risque accepté)**. `TinySensor/` n'est pas du code mort : il est conservé intentionnellement pour le workflow de debug/flash Atmel Studio (debugWIRE/JTAG), non remplaçable par PlatformIO. Score abaissé de 32 → 20, catégorie "risque de divergence à surveiller". Mitigations recommandées : commentaires croisés dans les deux `main.cpp` + step CI `diff` en warn-only. → **Requalifié, non supprimé**.
- **C2 (30) — Macro `OREGON_DELAY_US` morte supprimée**. La macro n'était jamais appelée (Oregon utilise `_hal->Delay512Us()/Delay1024Us()` directement) et référençait une méthode inexistante. Supprimée de `TestHal.h`. → **Résolu**.
- **C15 (15) — `override` ajouté sur les stubs de délai de `TestHal`**. `Delay400Us`, `Delay1024Us`, `Delay512Us` n'avaient pas `override` ; dérive de signature désormais détectable à la compilation. → **Résolu**.

- **C3 (20) — `Init()` orphelin supprimé**. Fonction libre `void Init(void)` en bas de `Attiny84aHal.cpp`, hors de la classe, jamais appelée — shadow silencieux de `Attiny84aHal::Init`. Supprimée. → **Résolu**.
- **C11 (15) — Branche morte `SetPressure` supprimée**. `if (pressure < 200) pressure = 200;` était immédiatement écrasé par le clamp à 850 ; supprimé. → **Résolu**.
- **D5 (20) — `avrdude.conf` sorti du repo**. Le fichier (534 KB) provient du toolchain PlatformIO (`~/.platformio/packages/tool-avrdude/`) ; supprimé avec `git rm`. → **Résolu**.
- **I3 — Requalifié**. Audit revisité : le ZIP KiCAD n'était pas tracké git (sur disque uniquement) ; `*.zip` déjà couvert par `.gitignore`. Non-issue, comme I1. → **Résolu (par prévention)**.
- **I2 (25) — Chemins absolus paramétrés**. `Makefile` : `PIO ?= $(HOME)/.platformio/penv/bin/pio`, `TARGET ?= S_03`, `cp` remplace `copy`. `scripts/flash_tinySensor` : `PIO_HOME` et `PROJECT_DIR` avec défauts portables (`${HOME}/.platformio` et `$(dirname $0)/..`). → **Résolu**.
- **D3 (24) + D4 (24) — Dépendances PlatformIO épinglées sur SHA**. Les 5 dépendances (BH1750, tiny-i2c, Unity, avr-ds18b20, SparkFun_BME280) épinglées sur leur commit HEAD courant dans `platformio.ini`. Reproductibilité garantie, risque supply-chain éliminé. → **Résolu**.
- **Doc1 (20) — `docs/environments.md` créé**. Convention `S_*` = numéro sur le PCB, guide de calibration `INTERNAL_1v1` par carte, table boards physiques + envs spéciaux (`robot`, `devmodule`, `SOLAR_TEST`), seuils batterie par chimie, procédure d'ajout d'une nouvelle carte. → **Résolu**.

Impact 2026-06-18 : **291 points** résolus (C1:35 + D1:36 + A4:15 + D6:12 + C2:30 + C15:15 + C3:20 + C11:15 + D5:20 + I2:25 + D3:24 + D4:24 + Doc1:20).

Impact cumulé toutes dates : **598 points** (307 + 291).

### 2026-06-19 — RBD setup, requirements reverse-engineering, architectural violations V1-V4

#### Infrastructure RBD

Le projet est passé sous **Requirement-Based Development (RBD)** via le plugin Claude Code `arcadien/rbd@0.12.0`. Cela comprend :

- `.rbd/config.yml` — ID format `FUNC/TECH/CONF/PLAT-DOMAIN-NNN`, framework Unity/C++, linter `clang-format`
- `.clang-format` — style Google, 2 espaces, 80 colonnes, `SortIncludes: false`
- Baseline clang-format appliquée sur tous les `.cpp`/`.h` existants (37 fichiers)
- `CLAUDE.md` mis à jour avec la section RBD (commit prefix obligatoire, `// @req {id}`, etc.)
- Pre-push hook `~/.claude/hooks/rbd-pre-push-check.sh` installé

#### Rétro-ingénierie des exigences

Analyse architecturale complète (`docs/analysis-2026-06-18.md`) suivie de 8 vagues de `requirement-analyst` agents en parallèle. **67 exigences validées et committées** :

| Fichier | Domaines | Nb exigences |
|---|---|:---:|
| `requirements/functional.md` | FUNC-OREGON, LACROSSE, X10, BATTERY, SENSOR, ANALOG | 37 |
| `requirements/technical.md` | TECH-HAL, FILTER, CONVERT, SERIAL, X10 | 14 |
| `requirements/configuration.md` | CONF-BUILD | 11 |
| `requirements/platform.md` | PLAT-POWER | 5 |
| **Total** | | **67** |

`docs/architecture.md` enrichi d'une table de traçabilité complète (67 lignes Requirement → Component).

#### Violations architecturales V1-V4 résolues

- **V1 — `x10rf` contournait le HAL pour tous les timings** : 5 fonctions statiques locales (`x10_preamble_high`, etc.) appelaient `_delay_us()` directement, violant `TECH-HAL-001`. Cycle RBD complet : TECH-X10-001 (5 nouvelles méthodes `Hal` : `DelayX10PreambleHigh` 8960 µs, `DelayX10PreambleLow` 4500 µs, `DelayX10BitShort` 560 µs, `DelayX10BitLong` 1120 µs, `DelayX10Gap` 40 000 µs) + TECH-X10-002 (x10rf remplacé — bloc `#if defined(AVR) _delay_us` supprimé, 5 appels `_hal->DelayX10*()` substitués). 14 nouveaux tests Unity. → **Résolu**. Note : **C6 (SoftSerial) reste ouvert** — même pattern, traitement séparé.

- **V2 — `#include <AnalogFilter.h>` mort dans `Attiny84aHal.cpp`** : inclus ligne 2, jamais référencé — `AdcRead` utilisait des variables locales. Supprimé. → **Résolu**.

- **V3 — `BH1750` absent de `docs/architecture.md`** : ajouté au diagramme Mermaid et à la table des responsabilités. → **Résolu**.

- **V4 — `ds18b20` absent de `docs/architecture.md`** : idem. → **Résolu**.

#### Devcontainer

- **DevContainer** : Node.js 20 LTS + `@anthropic-ai/claude-code` ajoutés à `.devcontainer/Dockerfile` (installation système via NodeSource). Claude Code désormais disponible après `Rebuild Container`.

#### C5 — Accès DS18B20 encapsulé dans la classe `Ds18b20`

- **C5 (20) — `main.cpp` accédait directement aux registres AVR pour DS18B20** (`ds18b20convert(&PORTA, &DDRA, &PINA, …)`). Cycle RBD complet : TECH-SENSOR-001 validé, 4 tests Unity natifs (`test/test_ds18b20/`), classe `include/Ds18b20.h` créée suivant exactement le patron `BMx280` (sections `#if defined(AVR)` / `#else` stub, constructeur `Hal*`). `main.cpp` réduit à `ds18b20sensor.Convert()` + `ds18b20sensor.Read()` — aucune référence résiduelle à `PORTA`/`DDRA`/`PINA`. → **Résolu**.

Impact 2026-06-19 : **20 points** résolus (C5:20). Score cumulé : **618 points** (598 + 20).

---

## 2. Méthodologie

Chaque item identifié est scoré selon la formule du framework tech-debt :

**Priorité = (Impact + Risque) × (6 − Effort)**

- **Impact** (1–5) : dans quelle mesure cela ralentit l'équipe ou dégrade la qualité ?
- **Risque** (1–5) : que se passe-t-il si on ne corrige pas ?
- **Effort** (1–5) : coût de la correction (1 = trivial, 5 = gros chantier).

Le plus haut score théorique est 50 ((5+5)×(6−1)). Je classe les items en quatre bandes :

| Bande | Score | Traitement |
|---|---|---|
| P0 — Critique | ≥ 30 | À traiter sous 1–2 semaines |
| P1 — Élevé | 20–29 | Sprint courant ou suivant |
| P2 — Moyen | 12–19 | Backlog qualité à dérouler sur un trimestre |
| P3 — Faible | < 12 | Opportuniste, quand on touche la zone |

---

## 3. Dette par catégorie

### 3.1 Dette de code

| ID | Item | Localisation | Impact | Risque | Effort | Priorité |
|----|---|---|:---:|:---:|:---:|:---:|
| ~~C1~~ | ~~Token Coveralls commité en clair (`repo_token: K1UMmvKnmugffPWriB48kR274KXcAuvuK`)~~ — ✅ **Résolu 2026-06-18** (token révoqué, déplacé en secret GitHub Actions `COVERALLS_REPO_TOKEN`) | `.coveralls.yml` | 2 | 5 | 1 | ~~35~~ |
| ~~C2~~ | ~~`TestHal` référence un `OREGON_DELAY_US(x) TestHal.Delay(x)` qui n'existe pas.~~ — ✅ **Résolu 2026-06-18** (macro jamais appelée — Oregon utilise `_hal->Delay512Us()/Delay1024Us()` directement ; macro morte supprimée) | `lib/hal/TestHal.h:74` | 3 | 3 | 1 | ~~30~~ |
| ~~C3~~ | ~~Fonction libre `void Init(void)` orpheline en bas de `Attiny84aHal.cpp`, hors de la classe, jamais appelée.~~ — ✅ **Résolu 2026-06-18** (fonction supprimée) | `lib/hal/Attiny84aHal.cpp:199-203` | 2 | 2 | 1 | ~~20~~ |
| ~~C4~~ | ~~Dead-code dans `OregonV3::Sum` : `if (int(count) != count)` est toujours faux pour un `uint8_t`.~~ — ✅ **Résolu 2026-06-16** (branche morte supprimée ; héritage d'une impl. internet avec `float count`) | `lib/oregon/Oregon_v3.cpp:82` | 2 | 2 | 1 | ~~20~~ |
| ~~C5~~ | ~~`main.cpp` fait des accès registres directs (`ds18b20convert(&PORTA, &DDRA, &PINA, (1 << 3), nullptr)`), contournant le HAL.~~ — ✅ **Résolu 2026-06-19** (classe `Ds18b20` créée dans `include/Ds18b20.h` — même patron que `BMx280` ; `main.cpp` appelle `ds18b20sensor.Convert()` / `ds18b20sensor.Read()`, plus aucune référence à `PORTA`/`DDRA`/`PINA` ; TECH-SENSOR-001 + 4 tests Unity) | `src/main.cpp:116,120` | 3 | 2 | 2 | ~~20~~ |
| C6 | `SoftSerial` utilise `_delay_us()` directement au lieu du HAL → impossible à tester en natif et rompt le contrat d'abstraction. | `lib/softSerial/SoftSerial.cpp:3-6,16,24,32,36` | 3 | 2 | 2 | **20** |
| ~~C7~~ | ~~Config per-env avec duplication massive dans `platformio.ini` : S_02, S_03, S_04, S_05, robot, devmodule, SOLAR_TEST partagent 80 % de leurs `build_flags`.~~ — ✅ **Résolu 2026-06-16** (`[env:avr_base]` + `extends` ; `default_envs` pour exclure la base des builds) | `platformio.ini` | 4 | 2 | 3 | ~~18~~ |
| C8 | Magic numbers non documentés : `PRESSURE_SCALING_VALUE = 795`, `MAX_ROLLING_CODE_VALUE = 0xA5` (non utilisée), `SYNC_NIBBLE = 0x0A` (non utilisée), timings X10 (`PREAMBLE_LOW = 4500`, etc.) sans référence datasheet. | `lib/oregon/Oregon_v3.cpp`, `lib/x10/x10rf.cpp` | 2 | 2 | 2 | **16** |
| C9 | `dec16ToHex` déborde silencieusement pour `input > 9999` (le test `conversionToolsTest.cpp` le prouve avec `10000 → 0xA000` marqué en commentaire "overflow"). Pas de `assert` ni de clamp. | `lib/utils/src/conversionTools.cpp:5-22` | 2 | 2 | 2 | **16** |
| ~~C10~~ | ~~`USE_BMP280=1` déclaré **deux fois** dans `env:S_03` (lignes 88 et 90) — copier-coller résiduel.~~ — ✅ **Résolu 2026-06-16** (subsumed par C7 ; la refacto `extends` a éliminé le doublon) | `platformio.ini:88,90` | 2 | 1 | 1 | ~~15~~ |
| ~~C11~~ | ~~Branche morte dans `LacrosseWS7000::SetPressure` : `if (pressure < 200) pressure = 200;` est immédiatement écrasé par `if (pressure < 850) pressure = 850;`.~~ — ✅ **Résolu 2026-06-18** (branche morte supprimée) | `lib/LacrosseWS7000/LacrosseWS7000.cpp:24-25` | 1 | 2 | 1 | ~~15~~ |
| C12 | Macro `BITREAD` redéfinie dans 4 fichiers (`Oregon_v3.cpp`, `LacrosseWS7000.cpp`, `x10rf.cpp`, `x10rf.h`) avec des variantes (`bitRead`, `BITREAD`). | (multiple) | 2 | 1 | 2 | **12** |
| C13 | HAL "leaky" : méthodes nommées `RadioGoHigh/Low`, `SerialGoHigh/Low` — pilotage sémantique d'IO, pas une vraie abstraction de bus radio. Un port sur un MCU sans GPIO configurable de la même façon obligera à retoucher le HAL. | `lib/hal/Hal.h` | 3 | 2 | 4 | **10** |
| C14 | TODO isolé : `// TODO: tests for other modes` | `test/test_x10/x10LibTest.cpp:130` | 2 | 2 | 3 | **12** |
| ~~C15~~ | ~~`TestHal::Delay400Us/Delay1024Us/Delay512Us` manquent `override`.~~ — ✅ **Résolu 2026-06-18** (`override` ajouté sur les trois méthodes) | `lib/hal/TestHal.h:41-44` | 2 | 1 | 1 | ~~15~~ |
| ~~M1~~ | ~~`PRR &= ~_BV(PRTIM1/PRADC)` logique inversée dans `UseLessPowerAsPossible()` : les périphériques restaient actifs (consommation inutile sur batterie).~~ — ✅ **Résolu 2026-06-16** (identifié par revue MAGI, corrigé en `\|=`) | `lib/hal/Attiny84aHal.cpp` | 3 | 3 | 1 | ~~30~~ |
| ~~M2~~ | ~~`OregonV3::SetChannel()` sans validation de bornes : channel > 3 corrompt silencieusement `message[2]` en écrasant les nibbles ID capteur.~~ — ✅ **Résolu 2026-06-16** (guard `if (channel < 1 \|\| channel > 3) return;` ajouté) | `lib/oregon/Oregon_v3.cpp` | 3 | 3 | 1 | ~~30~~ |
| ~~M3~~ | ~~`message[]` variable globale de fichier dans `Oregon_v3.cpp` — singleton accidentel : deux instances `OregonV3` auraient partagé le même buffer.~~ — ✅ **Résolu 2026-06-16** (déplacé en membre privé `uint8_t message[MESSAGE_SIZE_IN_BYTES]`) | `lib/oregon/Oregon_v3.cpp/.h` | 2 | 2 | 2 | ~~16~~ |

### 3.2 Dette d'architecture

| ID | Item | Impact | Risque | Effort | Priorité |
|----|---|:---:|:---:|:---:|:---:|
| A1 | **Arbre source dupliqué — risque accepté** : `TinySensor/` (projet Atmel Studio) est conservé intentionnellement pour le workflow de debug pas-à-pas et de flashage via debugWIRE/JTAG, que PlatformIO ne remplace pas complètement. Contient `main.cpp`, `bh1750.cpp/h`, `TinyI2CMaster.cpp/h` + `third_party/`. Risque résiduel : divergence silencieuse si un fix appliqué dans `src/` n'est pas reporté dans `TinySensor/main.cpp`. Mitigations recommandées : (1) commentaire croisé dans les deux `main.cpp` pointant l'un vers l'autre, (2) step CI `diff -u src/main.cpp TinySensor/main.cpp` en mode warn-only pour rendre la divergence visible. | 2 | 3 | 2 | **20** |
| A2 | Pas d'interface commune `EnvironmentEncoder` : `main.cpp` dispatche Oregon vs Lacrosse avec des `#if defined(USE_OREGON)/USE_LACROSSE` répétés 4× dans la même fonction. Ajouter un 3e protocole coûtera un passage dans toute la `main()`. | 3 | 2 | 3 | 15 |
| A3 | Le bloc BH1750 dans `main.cpp:155-168` instancie en ligne un `LacrosseWS7000 lightEncoder(&hal)` — logique capteur mélangée avec logique de transmission. | 3 | 2 | 2 | **20** |
| ~~A4~~ | ~~Web firmware builder (`web/build.php`) : `shell_exec` sans sanitisation des inputs.~~ — ✅ **Résolu 2026-06-18** (décision : supprimer `web/` ; builder jamais finalisé, jamais utilisé en production — `web/build.php` + `web/index.html` supprimés) | 2 | 3 | 3 | ~~15~~ |
| A5 | Configuration 100 % build-time : chaque capteur physique = un env PIO + une recompilation. Pas de config runtime, donc aucune mise à jour terrain sans reflashage manuel. Architecture acceptable pour un hobby / production très petite série ; limitante si on veut scaler. | 3 | 2 | 4 | 10 |
| A6 | HAL ATmega328p absent malgré mention README. Branche `feat/328p_hal` existe mais non mergée — code parallèle qui va dériver. | 2 | 1 | 4 | 6 |

### 3.3 Dette de tests

| ID | Item | Impact | Risque | Effort | Priorité |
|----|---|:---:|:---:|:---:|:---:|
| ~~T1~~ | ~~**La CI ne compile aucune cible AVR**. Le workflow ne lance que `pio test -e native_debug`. Un refactor peut casser `S_02`..`SOLAR_TEST` sans alerte. Le projet "prod" n'est jamais vérifié.~~ — ✅ **Résolu 2026-04-19** (workflow à deux jobs, matrice AVR) | 5 | 4 | 2 | ~~36~~ |
| T2 | Pas de rapport de couverture actif. `.coveralls.yml` existe (et est compromis, cf. C1), mais aucune étape CI ne génère/upload la couverture. | 2 | 1 | 2 | 12 |
| T3 | Pas de test pour le wrapper `BMx280` (le fichier d'en-tête expose `GetTemperature/GetHumidity/GetPressure`, aucun test ne vérifie les passerelles). | 3 | 2 | 3 | 15 |
| T4 | Pas de test pour `SoftSerial` — blocage lié à C6 (dépendance à `_delay_us`). | 2 | 2 | 2 | **16** |
| T5 | Pas de test HW-in-the-loop ni Simavr-based exécuté en CI, malgré la présence de `[env:SOLAR_TEST]` configuré pour simavr. Infrastructure prête mais non exploitée. | 3 | 3 | 4 | 12 |
| T6 | Les tests de timings Oregon/Lacrosse valident une *chaîne de caractères d'ordres* (`"LDH PLD"` = 1, `"HDL PHD"` = 0) via `TestHal.Orders`. C'est élégant mais ne vérifie pas les timings réels ni l'interop avec RTL_433/RFLink que le README cite comme référence. | 3 | 3 | 4 | 12 |
| T7 | `test_busses/bussesTest.cpp` ne teste qu'un booléen `I2CIsConfigured` après `Init()` — valeur de régression nulle. | 2 | 1 | 2 | 12 |

### 3.4 Dette de dépendances

| ID | Item | Impact | Risque | Effort | Priorité |
|----|---|:---:|:---:|:---:|:---:|
| ~~D1~~ | ~~**Image Docker `php:7.4-apache` EOL depuis novembre 2022.** Utilisée comme base du firmware builder web.~~ — ✅ **Résolu 2026-06-18** (supprimé avec `web/` — plus de Dockerfile PHP dans le repo) | 4 | 5 | 2 | ~~36~~ |
| ~~D2~~ | ~~GitHub Actions obsolètes : `actions/checkout@v3`, `actions/cache@v3`, `actions/setup-python@v4`. Python 3.9 utilisé — EOL octobre 2025 (nous sommes en avril 2026).~~ — ✅ **Résolu 2026-04-19** (v4/v4/v5, Python 3.12) | 3 | 3 | 1 | ~~30~~ |
| ~~D3~~ | ~~Dépendances PlatformIO tirées de forks personnels sans épinglage de commit.~~ — ✅ **Résolu 2026-06-18** (toutes les 5 dépendances épinglées sur leur SHA HEAD courant dans `platformio.ini`) | 4 | 4 | 3 | ~~24~~ |
| ~~D4~~ | ~~`bh1750` épinglé sur la branche `feat/attiny_support` au lieu d'un SHA.~~ — ✅ **Résolu 2026-06-18** (subsumed par D3 — épinglé sur `6d06b87`) | 3 | 3 | 2 | ~~24~~ |
| ~~D5~~ | ~~`avrdude.conf` (534 KB) commité dans le repo.~~ — ✅ **Résolu 2026-06-18** (`git rm avrdude.conf` ; vient du toolchain PlatformIO, pas de la source) | 2 | 2 | 1 | ~~20~~ |
| ~~D6~~ | ~~`web/build.php` charge jQuery 1.12.4 depuis CDN (sortie 2016, EOL).~~ — ✅ **Résolu 2026-06-18** (supprimé avec `web/`) | 1 | 2 | 2 | ~~12~~ |
| D7 | Copies tierces vendored dans `TinySensor/third_party/` (BMX, I2C, X10) figées, risque de divergence vs. upstream. | 2 | 2 | 2 | 16 |
| ~~D8~~ | ~~Badge README pointe vers **Travis CI** (`api.travis-ci.org`) — service fermé aux OSS non payants depuis 2020. Badge cassé = signal négatif pour les contributeurs.~~ — ✅ **Résolu 2026-06-16** (badge GitHub Actions dans `README.md`) | 1 | 1 | 1 | ~~10~~ |
| ~~D9~~ | ~~Pas de configuration Dependabot/Renovate. Dérive des versions non notifiée.~~ — ✅ **Résolu 2026-06-16** (`.github/dependabot.yml` : hebdomadaire pour `github-actions`, mensuel pour `docker` + `pip`) | 2 | 3 | 1 | ~~25~~ |

### 3.5 Dette de documentation

| ID | Item | Impact | Risque | Effort | Priorité |
|----|---|:---:|:---:|:---:|:---:|
| ~~Doc1~~ | ~~Sémantique des environnements `S_02`..`S_05` non documentée.~~ — ✅ **Résolu 2026-06-18** (`docs/environments.md` créé : convention de nommage PCB, guide de calibration `INTERNAL_1v1`, table des boards physiques et envs spéciaux, seuils batterie) | 3 | 2 | 2 | ~~20~~ |
| Doc2 | Pas de guide d'onboarding (stack requise, setup local, premier build). Le README est orienté utilisateur/hardware, pas contributeur. | 3 | 2 | 2 | **20** |
| Doc3 | Workflow de flashage non documenté : `scripts/flash_tinySensor` + `waitForUpload` supposent une organisation NAS spécifique (`/var/services/homes/aurelien/…`). | 2 | 2 | 2 | 16 |
| Doc4 | Spécifications Oregon et Lacrosse référencées en commentaires (*"A copy of the document should be provided along the implementation"*) mais les docs PDF ne sont pas au repo. Lien externe ou fichier embarqué requis. | 2 | 2 | 2 | 16 |
| Doc5 | Absent : `CONTRIBUTING.md`, `SECURITY.md` (surtout pertinent vu C1), `CODE_OF_CONDUCT.md`, `CHANGELOG.md`. | 2 | 1 | 2 | 12 |
| Doc6 | Hardware : pas de BOM consolidé, pas de guide d'assemblage dans `doc/` (seulement 3 images : `boardv2.png`, `boardv2_copper.png`, `schematic.png`). | 2 | 1 | 3 | 9 |
| ~~Doc7~~ | ~~Badge Travis cassé dans README (doublon avec D8, traité côté deps).~~ — ✅ **Résolu 2026-06-16** (badge remplacé par GitHub Actions dans `README.md`) | 1 | 1 | 1 | ~~10~~ |

### 3.6 Dette d'infrastructure

| ID | Item | Impact | Risque | Effort | Priorité |
|----|---|:---:|:---:|:---:|:---:|
| ~~I1~~ | ~~**Artefacts de build commités** dans `TinySensor/Debug/` : `.o`, `.d`, `.elf`, `.hex`, `.lss`, `.map`, `.srec`.~~ — ✅ **Résolu 2026-04-19** (audit revisité : aucun artefact n'était réellement tracké ; `TinySensor/Debug/` désormais couvert par `.gitignore`). | 3 | 2 | 1 | ~~25~~ |
| ~~I2~~ | ~~Chemins absolus spécifiques à l'auteur dans `Makefile` et `scripts/flash_tinySensor`.~~ — ✅ **Résolu 2026-06-18** (`PIO ?= $(HOME)/.platformio/penv/bin/pio`, `TARGET ?= S_03` dans `Makefile` ; `PIO_HOME` et `PROJECT_DIR` avec défauts `${HOME}/.platformio` et `$(dirname $0)/..` dans le script) | 3 | 2 | 1 | ~~25~~ |
| ~~I3~~ | ~~Archive de backup KiCAD commitée (`tinySensorv1-2025-05-01_183922.zip`).~~ — ✅ **Résolu 2026-06-18** (audit revisité : le ZIP n'était pas tracké par git — sur disque uniquement ; `*.zip` déjà couvert par `.gitignore`) | 2 | 2 | 1 | ~~20~~ |
| ~~I4~~ | ~~La CI ne produit aucun artefact (firmware `.hex` téléchargeable).~~ — ✅ **Résolu 2026-06-16** (job `release` ajouté sur `v*` tags : télécharge tous les artefacts et publie une GitHub Release avec notes auto-générées — complète la résolution partielle du 2026-04-19) | 2 | 1 | 2 | ~~12~~ |
| I5 | CI single-runner, single-python, single-env. Pas de matrice pour tester différentes versions d'outillage. | 3 | 2 | 2 | **20** |
| I6 | Pas de pre-commit ni de `.editorconfig`. `clang-format` est installé dans le devcontainer mais non appliqué automatiquement (le commit `68cefb8 chore: clang-format` laisse penser à une passe manuelle ponctuelle). | 2 | 1 | 2 | 12 |
| ~~I7~~ | ~~`.gitignore` minimaliste (12 lignes) : n'exclut pas `Debug/` (d'où I1), pas `*.o`, `*.d`, `*.hex` au root.~~ — ✅ **Résolu 2026-04-19** (ligne 1 buggée supprimée, patrons d'artefacts ajoutés, structure commentée). | 2 | 2 | 1 | ~~20~~ |
| I8 | Pas de release / tag git visible sur les 30 derniers commits. Versioning absent. | 2 | 1 | 2 | 12 |

---

## 4. Classement prioritaire (top 20)

> Les items barrés ont été traités depuis la publication initiale (cf. §1bis). Ils restent listés pour traçabilité de l'effort consenti.

| Rang | ID | Item | Cat. | Score |
|:----:|----|---|:----:|:-----:|
| — | ~~T1~~ | ~~CI ne compile aucune cible AVR~~ ✅ | Test | ~~36~~ |
| — | ~~D1~~ | ~~Image Docker PHP 7.4 EOL~~ ✅ | Dep | ~~36~~ |
| — | ~~C1~~ | ~~Token Coveralls en clair dans le repo~~ ✅ | Code | ~~35~~ |
| — | ~~A1~~ | ~~Arbre source dupliqué `TinySensor/`~~ → requalifié, risque accepté (score 20, voir §3.2) | Archi | ~~32~~ |
| — | ~~D2~~ | ~~GitHub Actions obsolètes + Python 3.9 EOL~~ ✅ | Dep | ~~30~~ |
| — | ~~C2~~ | ~~Macro `OREGON_DELAY_US` réfère une méthode inexistante~~ ✅ | Code | ~~30~~ |
| — | ~~M1~~ | ~~PRR bit inversé dans `UseLessPowerAsPossible()`~~ ✅ | Code | ~~30~~ |
| — | ~~M2~~ | ~~`SetChannel()` sans validation de bornes~~ ✅ | Code | ~~30~~ |
| — | ~~D9~~ | ~~Pas de Dependabot/Renovate~~ ✅ | Dep | ~~25~~ |
| — | ~~I1~~ | ~~Artefacts de build commités (`Debug/`)~~ ✅ | Infra | ~~25~~ |
| — | ~~I2~~ | ~~Chemins absolus auteur dans Makefile/scripts~~ ✅ | Infra | ~~25~~ |
| — | ~~D3~~ | ~~Deps pointent vers forks personnels non épinglés~~ ✅ | Dep | ~~24~~ |
| — | ~~D4~~ | ~~`bh1750` épinglé sur une branche au lieu d'un tag/SHA~~ ✅ | Dep | ~~24~~ |
| — | ~~C3~~ | ~~`Init()` orphelin dans `Attiny84aHal.cpp`~~ ✅ | Code | ~~20~~ |
| — | ~~C4~~ | ~~Dead-code `if (int(count) != count)` dans `Sum`~~ ✅ | Code | ~~20~~ |
| 8 | C5 | `main.cpp` accède aux registres sans passer par le HAL | Code | 20 |
| 8 | C6 | `SoftSerial` utilise `_delay_us` directement (non testable) | Code | 20 |
| 8 | A3 | Logique BH1750 mélangée dans `main.cpp` | Archi | 20 |
| — | ~~D5~~ | ~~`avrdude.conf` (534 KB) commité~~ ✅ | Dep | ~~20~~ |
| — | ~~Doc1~~ | ~~Envs `S_0x` non documentés (tribal knowledge)~~ ✅ | Doc | ~~20~~ |
| 8 | Doc2 | Pas de guide d'onboarding | Doc | 20 |
| — | ~~I3~~ | ~~Backup ZIP KiCAD commité~~ → non tracké git ✅ | Infra | ~~20~~ |
| 8 | I5 | Matrice CI inexistante | Infra | 20 |
| — | ~~I7~~ | ~~`.gitignore` minimaliste~~ ✅ | Infra | ~~20~~ |
| — | ~~M3~~ | ~~`message[]` variable globale partagée entre instances~~ ✅ | Code | ~~16~~ |
| — | ~~C7~~ | ~~Duplication massive `platformio.ini`~~ ✅ | Code | ~~18~~ |
| — | ~~C10~~ | ~~`USE_BMP280=1` en double dans `env:S_03`~~ ✅ | Code | ~~15~~ |
| — | ~~I4~~ | ~~Pas de release automation sur tag~~ ✅ | Infra | ~~12~~ |
| — | ~~D8~~ | ~~Badge Travis mort~~ ✅ | Dep | ~~10~~ |

---

## 5. Plan de remédiation phasé

Plan dimensionné pour 1 développeur à ~20 % de son temps. Chaque phase s'intercale avec du travail feature ; aucune ne bloque les autres.

### Phase 0 — Sécurité immédiate (jour 0–1, < 2 h)

Un seul item, non négociable : **révoquer le token Coveralls** (`C1`). Révoquer côté coveralls.io, supprimer le token du fichier, le déplacer dans un secret GitHub Actions `COVERALLS_REPO_TOKEN`, et adapter le workflow. Même si le repo est public et que l'expo a déjà eu lieu, la rotation est obligatoire.

### Phase 1 — Stabilisation CI & outillage (semaine 1–2, ~1 jour) — **partiellement faite 2026-04-19**

Objectif : ne plus pouvoir casser le firmware de prod sans le voir dans la CI, et remettre l'outillage au goût du jour.

Actions, par ordre de valeur :

1. ~~**T1 — Ajouter la compilation AVR à la CI**. Étendre `.github/workflows/main.yml` avec une matrice qui fait `pio run -e S_02 -e S_03 -e S_04 -e S_05 -e robot -e devmodule` en plus du `pio test -e native_debug`. Coût : 30 min.~~ ✅ **Fait 2026-04-19** (matrice sur 7 envs, `fail-fast: false`).
2. ~~**D2 — Mettre à jour les Actions** : `checkout@v4`, `cache@v4`, `setup-python@v5`, Python `3.12`. Coût : 15 min.~~ ✅ **Fait 2026-04-19**.
3. ~~**I1, I7 — Nettoyer les artefacts versionnés**. Ajouter à `.gitignore` : `Debug/`, `Release/`, `*.o`, `*.d`, `*.elf`, `*.hex` (root seulement), `*.lss`, `*.map`, `*.srec`, `TinySensor/Debug/`. Puis `git rm -r --cached TinySensor/Debug/` et commit.~~ ✅ **Fait 2026-04-19** (cf. §1bis ; `git rm --cached` s'est révélé no-op, aucun artefact n'était réellement tracké).
4. **I2 — Paramétrer les scripts**. Remplacer les chemins absolus du `Makefile` et de `scripts/flash_tinySensor` par des variables d'environnement (`PIO_HOME`, `PROJECT_DIR`). Documenter dans le README. Coût : 1 h.
5. **D9 — Activer Dependabot** (`.github/dependabot.yml`) pour `github-actions`, `docker`, `pip` (le python utilisé dans les scripts). Coût : 10 min.
6. **D8 + Doc7 — Retirer le badge Travis**, ajouter le badge GitHub Actions. Coût : 5 min.
7. **I4 (partie restante) — Release automation sur tag** : workflow `on: push: tags: ['v*']` qui rejoue la matrice et publie les `.hex` / `.elf` en GitHub Release. Coût : 1 h. *Déplacé ici depuis la phase 4 car le socle artefacts est désormais en place.*

Livrable de fin de phase : CI verte sur **toutes les cibles AVR + natif** (atteint), plus aucune modification ne peut casser silencieusement un firmware de production (atteint), artefacts téléchargeables par build (atteint), et releases taguées automatiques (à faire).

### Phase 2 — Consolidation de l'arbre source (semaine 3–5, ~3 jours cumulés)

Objectif : une seule source de vérité pour chaque fichier, dépendances reproductibles.

1. **A1 — Décision sur `TinySensor/` (legacy Atmel Studio)**. Deux options :
    - (a) Supprimer intégralement le dossier. C'est ce que je recommande : le projet PlatformIO couvre tout l'usage, Atmel Studio n'est plus maintenu (Microchip Studio 7.0 également en fin de support). Coût : 10 min + audit de ce qui serait perdu.
    - (b) Le conserver en tant que branche ou submodule séparé, hors de `master`.
    Action : ouvrir une PR "remove legacy Atmel Studio tree" avec une fenêtre de confirmation d'une semaine.
2. **D3, D4 — Épingler les dépendances PlatformIO**. Passer de `url.git#branch` à `url.git#<SHA>` (ou mieux, créer des tags `v1.0.0` sur chaque fork et utiliser `#v1.0.0`). Coût : 1 h.
3. **D5 — Sortir `avrdude.conf`** du repo. La config vient du paquet `tool-avrdude` de PlatformIO ; documenter dans le README et ajouter au `.gitignore`. Coût : 15 min.
4. **I3 — Supprimer le backup ZIP KiCAD**. L'historique git suffit. Coût : 5 min.
5. **D1 — Migrer le Dockerfile** de `php:7.4-apache` vers `php:8.3-apache` (ou plus récent). Tester le build. Coût : 2 h + test.

Livrable : un seul arbre source, deps reproductibles, image Docker à jour.

### Phase 3 — Qualité du code firmware (semaine 6–9, ~3 jours cumulés)

Objectif : éliminer la dette de code identifiée, renforcer les tests.

Quick wins (1 h chacun) :

1. **C2** — Corriger la macro `OREGON_DELAY_US` dans `TestHal.h`.
2. **C3** — Supprimer la fonction libre `Init()` orpheline.
3. **C4** — Supprimer le `if` mort dans `OregonV3::Sum`.
4. **C10** — Dédupliquer `USE_BMP280=1` dans `env:S_03`.
5. **C11** — Retirer le `if (pressure < 200)` mort.
6. **C15** — Ajouter `override` sur toutes les méthodes virtuelles de `TestHal`.

Refactorings moyens (1 jour chacun) :

7. **C5 + A3** — Encapsuler les accès DS18B20 et BH1750 derrière des classes capteurs (`Ds18b20Sensor`, `Bh1750Sensor`) utilisant le HAL. Alignerait sur le pattern `BMx280`.
8. **C6 + T4** — Refactorer `SoftSerial` pour passer toutes les temporisations par le HAL (`hal->DelayBitPeriod()` ou similaire). Ajouter un test natif de `SoftSerial` qui vérifie la séquence de `SerialGoHigh/Low` pour un caractère connu.
9. **C7 — Dédupliquer `platformio.ini`** : utiliser `[env:base_avr]` héritée par `[env:S_02]`, etc. (feature native de PlatformIO via `extends = env:base_avr`). Coût : 2 h + test.
10. **C12** — Centraliser `BITREAD` dans `lib/utils/include/bitops.h` et supprimer les redéfinitions.
11. **T3** — Ajouter un test unitaire pour `BMx280` en mode non-AVR (vérifie que les stubs renvoient 0 sans crash).
12. **C8** — Documenter les magic numbers (commentaire avec référence datasheet + lien).

### Phase 4 — Architecture & documentation (trimestre Q2/Q3, au fil de l'eau)

1. **A2** — Introduire une interface `IEnvironmentEncoder` partagée par `OregonV3` et `LacrosseWS7000`, injectée dans `main()`. Simplifie l'ajout de futurs protocoles.
2. **A4** — Statuer sur le sort de `web/` : (a) le finir (formulaire + sanitisation) ou (b) le supprimer et documenter un builder local. Je recommande (b) vu l'état.
3. **Doc1, Doc2** — Écrire `docs/environments.md` (quel env pour quelle carte physique) et `docs/CONTRIBUTING.md` (stack, premier build, architecture HAL/encoders).
4. **Doc5** — Créer `SECURITY.md` (processus de report) et `CHANGELOG.md` (tenir à jour sur les prochaines releases).
5. **I5 — Matrice d'outillage** : étendre la matrice existante à plusieurs Pythons (`3.11`, `3.12`, `3.13`) et/ou plusieurs versions de PlatformIO Core. (La partie release automation d'I4 a été remontée en Phase 1.)
6. **T5, T6 — Élever la barre des tests** : intégrer `simavr` dans la CI pour au moins un env (`SOLAR_TEST` est prêt), et ajouter un test d'intégration qui fait passer la trame Oregon au décodeur RTL_433 (binaire installable en CI) pour valider l'interop réelle.
7. **A5 — Évaluation** : runtime config via EEPROM ? Pertinent seulement si on vise plus de 5 unités en production. Ne pas faire avant d'en avoir le besoin.

---
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

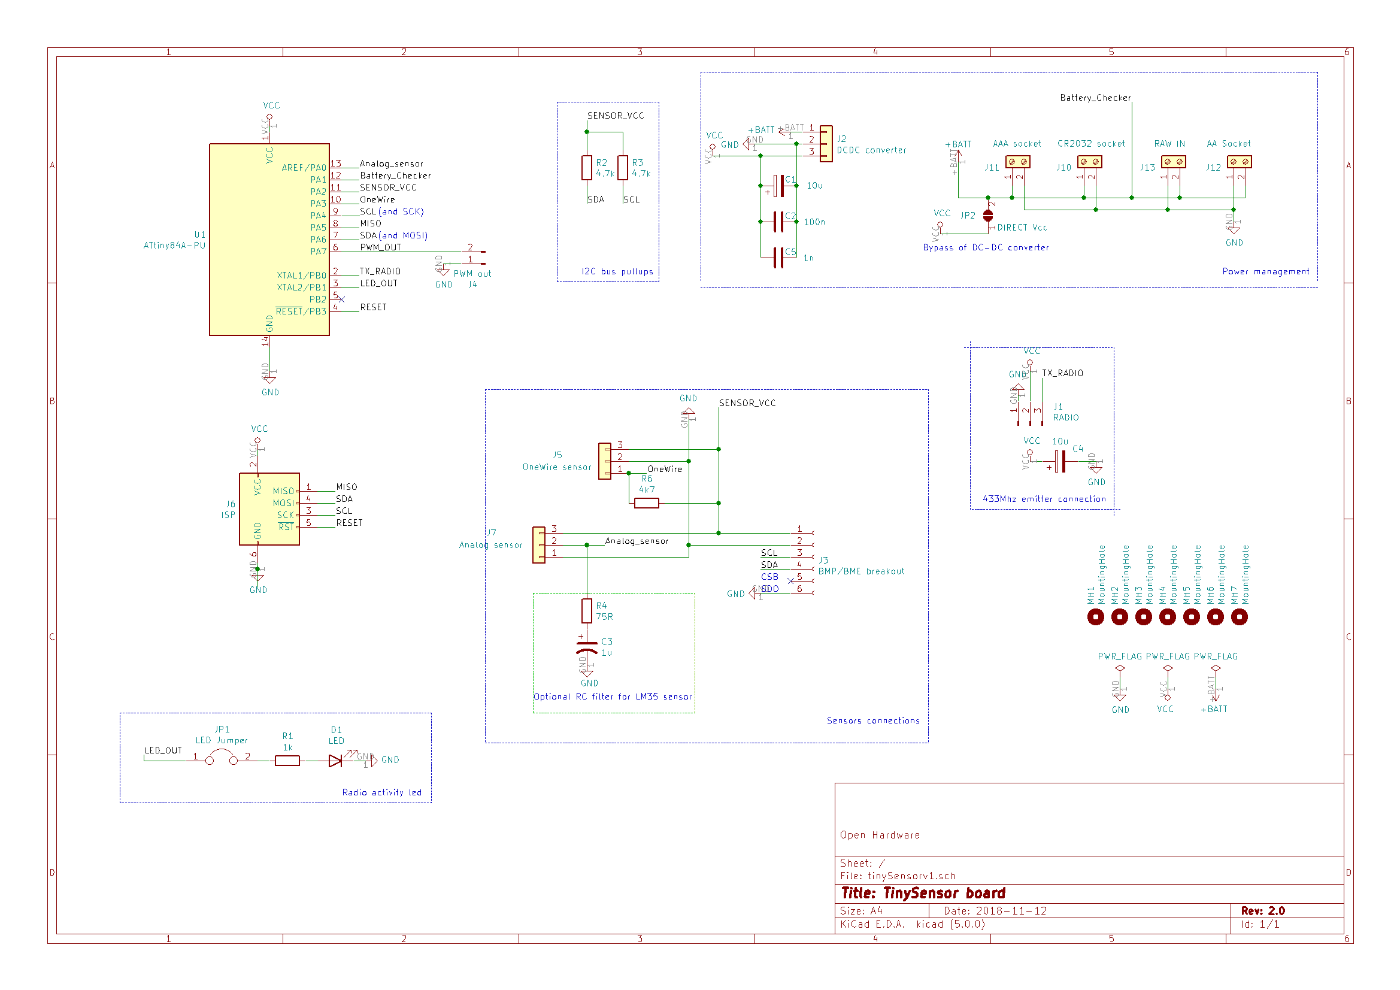
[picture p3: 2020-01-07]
doc/schematic.png

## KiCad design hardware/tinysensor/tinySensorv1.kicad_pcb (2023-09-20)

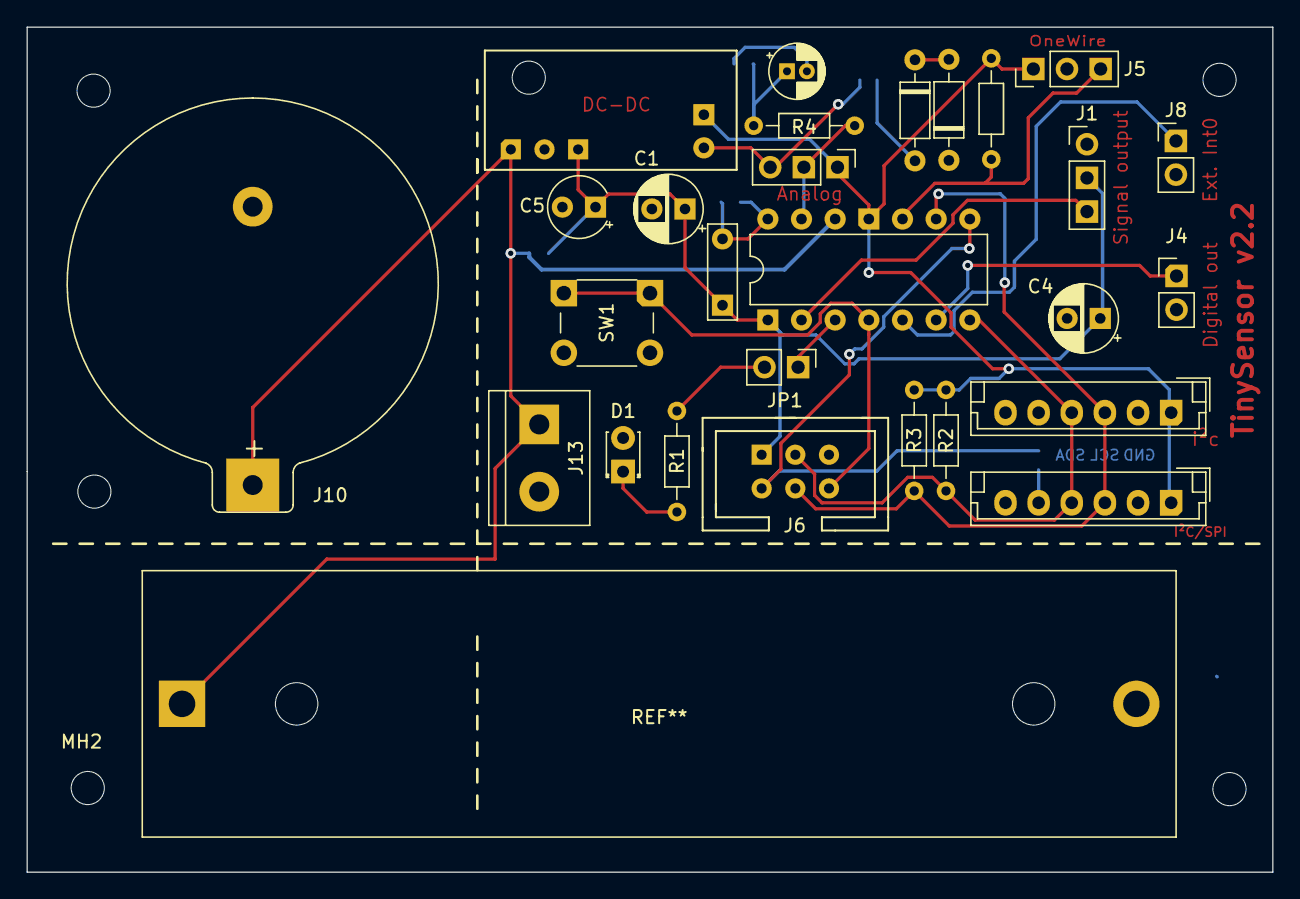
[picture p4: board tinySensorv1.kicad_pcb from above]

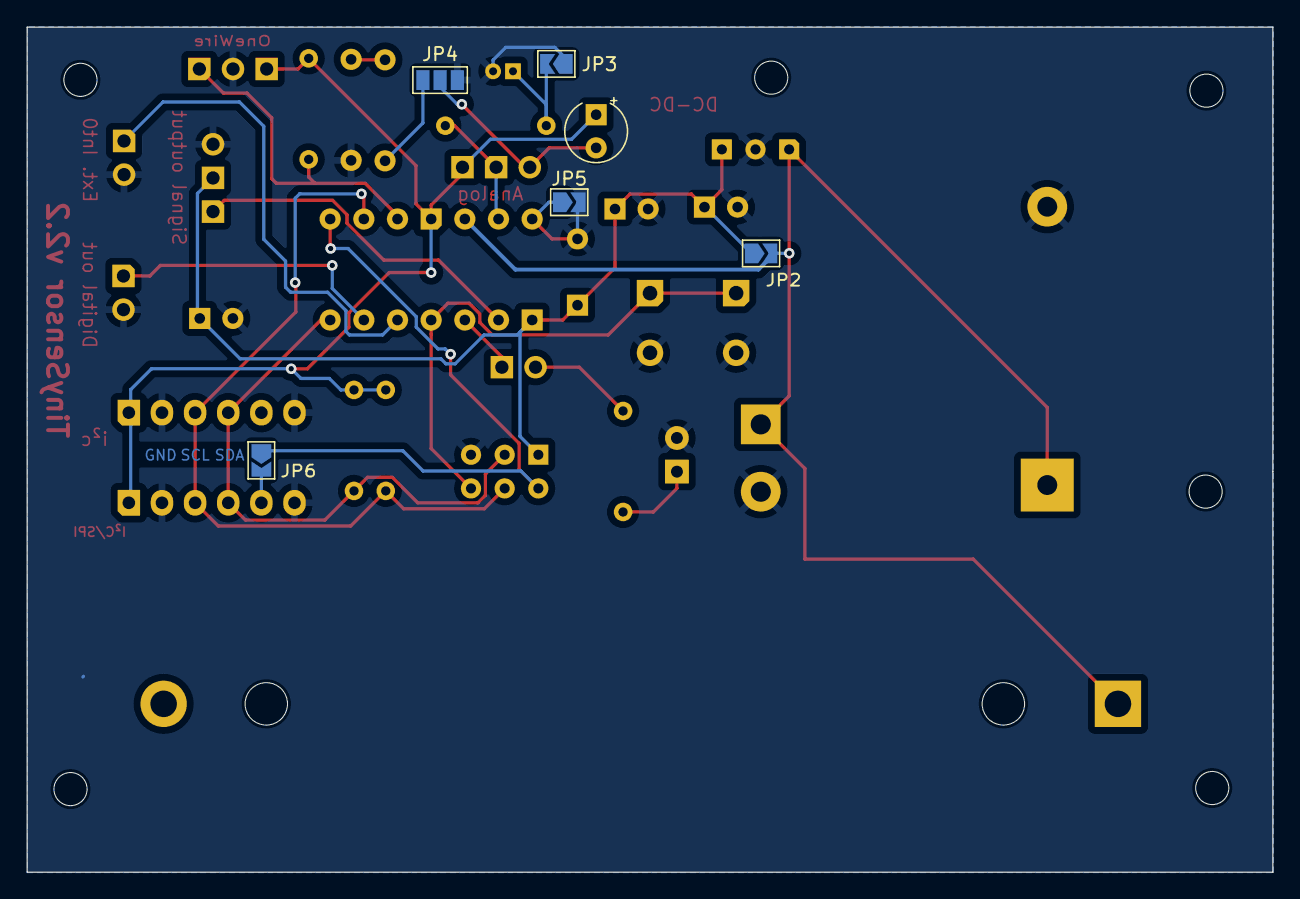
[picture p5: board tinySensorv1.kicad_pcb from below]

Board: 2 copper layers, 94.0 x 63.8 mm, 39 parts (6 on the bottom side), 20 nets.

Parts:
C1, C4: 10u; CP_Radial_D5.0mm_P2.50mm
C2: 100n; C_Rect_L7.0mm_W2.0mm_P5.00mm
C3: 1u; CP_Radial_D4.0mm_P1.50mm
C5: 1n; CP_Radial_Tantal_D4.5mm_P2.50mm
C6: 0.1u; CP_Radial_Tantal_D4.5mm_P2.50mm
D1: LED; LED_D1.8mm_W3.3mm_H2.4mm
D2, D3: 1N914; D_DO-35_SOD27_P7.62mm_Horizontal
I2C, I2C_SPI: JST_EH_B6B-EH-A_1x06_P2.50mm_Vertical
J1: RADIO; PinHeader_1x03_P2.54mm_Vertical
J2: DCDC converter; DC-DC_0.9v-3.3v_to_3.3v
J4: Digital out; PinHeader_1x02_P2.54mm_Vertical
J5: OneWire sensor; PinHeader_1x03_P2.54mm_Vertical
J6: ISP; ICSP_SOCKET_MINI_2x3
J7: Analog sensor; PinHeader_1x03_P2.54mm_Vertical
J8: EXT. INT0; PinHeader_1x02_P2.54mm_Vertical
J10: CR2032 socket; BatteryHolder_Keystone_106_1x21mm
J13: RAW IN; TerminalBlock_bornier-2_P5.08mm
JP1: LED Jumper; PinHeader_1x02_P2.54mm_Vertical
JP2, JP6: DIRECT Vcc; SolderJumper-2_P1.3mm_Open_TrianglePad1.0x1.5mm
JP3, JP5: SolderJumper-2_P1.3mm_Open_TrianglePad1.0x1.5mm
JP4: Analog ref; SolderJumper-3_P1.3mm_Open_Pad1.0x1.5mm_NumberLabels
MH1, MH1#2, MH2, MH4, MH5, MH6: MountingHole; MountingHole_2.5mm
R1: 1k; R_Axial_DIN0204_L3.6mm_D1.6mm_P7.62mm_Horizontal
R2, R3: 4,7k; R_Axial_DIN0204_L3.6mm_D1.6mm_P7.62mm_Horizontal
R4: 75R; R_Axial_DIN0204_L3.6mm_D1.6mm_P7.62mm_Horizontal
R6: 4k7; R_Axial_DIN0204_L3.6mm_D1.6mm_P7.62mm_Horizontal
SW1: RESET; SW_PUSH_6mm_H4.3mm
U1: ATtiny84A-PU; DIP-14_W7.62mm

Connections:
+BATT: J2.1, J10.1, J13.1, JP2.2 (B), U1.12 (PA1)
/Analog_sensor: J7.2, R4.1, U1.13 (AREF/PA0)
/DIGITAL_OUT: J4.1, U1.6 (PA7)
/INT0: J8.1, U1.5 (PB2)
/LED_OUT: JP1.1, U1.3 (XTAL2/PB1)
/MISO: I2C_SPI.5, J6.1 (MISO), JP6.1 (A), JP6.2 (B), U1.8 (PA5)
/OneWire: J5.3, R6.1, U1.10 (PA3)
/RESET: J6.5 (~RST), SW1.1, U1.4 (~RESET/PB3)
/SCL: I2C.3, I2C_SPI.3, J6.3 (SCK), R3.2, U1.9 (PA4)
/SDA: I2C.4, I2C_SPI.4, J6.4 (MOSI), R2.2, U1.7 (PA6)
/SENSOR_VCC: C6.1, I2C.1, I2C_SPI.1, J5.1, J7.1, R2.1, R3.1, R6.2, U1.11 (PA2)
/TX_RADIO: J1.3, U1.2 (XTAL1/PB0)
GND: C1.2, C2.1, C3.2, C4.2, C5.2, D1.2 (A), D3.1 (K), I2C.2, I2C.6, I2C_SPI.2, I2C_SPI.6, J1.1, J2.2, J4.2, J5.2, J6.6 (GND), J8.2, J10.2, J13.2, JP3.1 (A), JP4.3 (B), JP5.1 (A), JP5.2 (B), SW1.2, U1.14 (GND)
unnamed: D1.1 (K), R1.1
unnamed: D2.2 (A), JP4.1 (A)
unnamed: D2.1 (K), D3.2 (A)
unnamed: C6.2, J7.3, JP4.2 (C)
unnamed: JP1.2, R1.2
unnamed: C3.1, JP3.2 (B), R4.2
VCC: C1.1, C2.2, C4.1, C5.1, J1.2, J2.3, J6.2 (VCC), JP2.1 (A), U1.1 (VCC)

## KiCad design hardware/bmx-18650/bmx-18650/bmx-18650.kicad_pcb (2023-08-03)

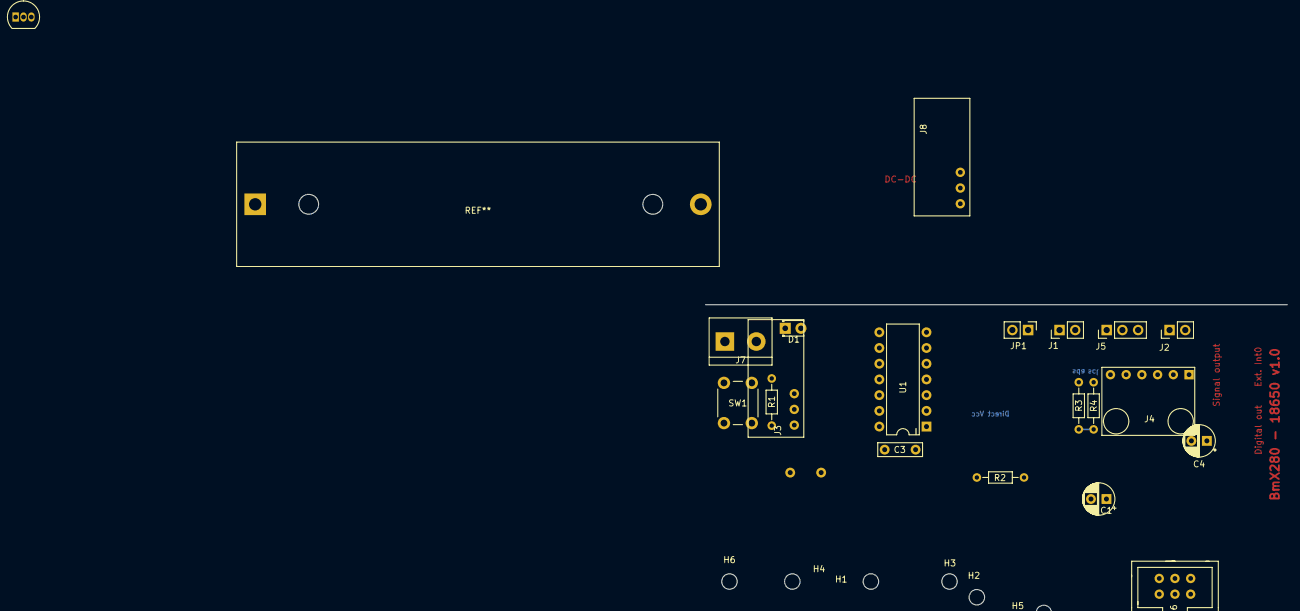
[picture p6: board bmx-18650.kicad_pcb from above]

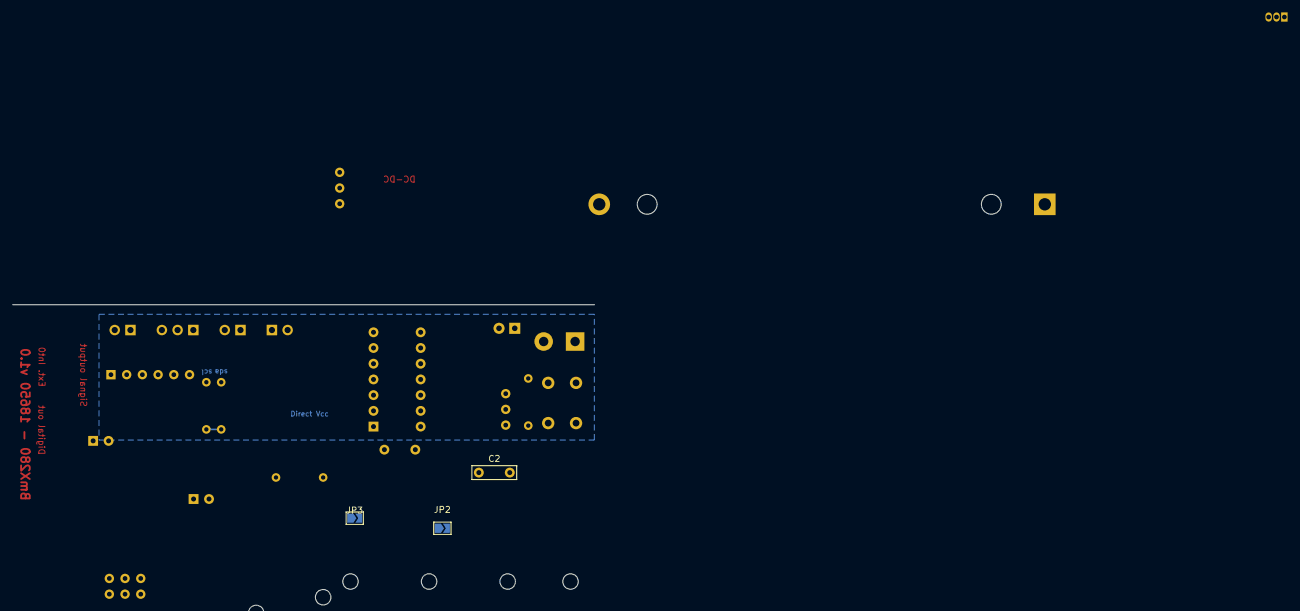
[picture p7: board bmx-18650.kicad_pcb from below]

Board: 2 copper layers, 29 parts (3 on the bottom side), 17 nets.

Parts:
C1, C4: 10u; CP_Radial_D5.0mm_P2.50mm
C2, C3: 100n; C_Rect_L7.0mm_W2.0mm_P5.00mm
D1: LED; LED_D1.8mm_W3.3mm_H2.4mm
H1, H2, H3, H4, H5, H6: MountingHole; MountingHole_2.5mm
J1: Ext. interrupt; PinHeader_1x02_P2.54mm_Vertical
J2: Digital out; PinHeader_1x02_P2.54mm_Vertical
J3: VCC charge pump; DC-DC_0.9v-3.3v_to_3.3v
J4: BMx280 socket; BMx280_breakout
J5: Radio emitter; PinHeader_1x03_P2.54mm_Vertical
J6: ISP; ICSP_SOCKET_MINI_2x3
J7: Terminal; TerminalBlock_bornier-2_P5.08mm
J8: RF charge pump; DC-DC_0.9v-3.3v_to_3.3v
JP1: LED Jumper; PinHeader_1x02_P2.54mm_Vertical
JP2, JP3: Bypass; SolderJumper-2_P1.3mm_Open_TrianglePad1.0x1.5mm
Q1: BS170; TO-92_Inline
R1, R3, R4: R; R_Axial_DIN0204_L3.6mm_D1.6mm_P7.62mm_Horizontal
R2: 10k; R_Axial_DIN0204_L3.6mm_D1.6mm_P7.62mm_Horizontal
SW1: SW_Push; SW_PUSH_6mm_H4.3mm
U1: ATtiny84A-PU; DIP-14_W7.62mm

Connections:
+BATT: J3.1, J7.1, J8.3, JP2.2 (B), JP3.1 (A), U1.12 (PA1)
/DIGITAL_OUT: J2.1, U1.6 (PA7)
/INT0: J1.1, U1.5 (PB2)
/LED_OUT: JP1.1, U1.3 (XTAL2/PB1)
/MISO: J6.1 (MISO), U1.8 (PA5)
/RESET: J6.5 (~RST), R2.1, SW1.1, U1.4 (~RESET/PB3)
/SCL: J4.3, J6.3 (SCK), R4.2, U1.9 (PA4)
/SDA: J4.4, J6.4 (MOSI), R3.2, U1.7 (PA6)
/SENSOR_VCC: J4.1, Q1.2 (G), R3.1, R4.1, U1.11 (PA2)
/TX_RADIO: J5.3, U1.2 (XTAL1/PB0)
GND: C1.2, C2.2, C3.1, C4.2, D1.2 (A), J1.2, J2.2, J3.2, J4.2, J4.6, J5.1, J6.6 (GND), J7.2, Q1.3 (S), SW1.2, U1.14 (GND)
unnamed: D1.1 (K), R1.1
unnamed: J8.2, Q1.1 (D)
unnamed: JP1.2, R1.2
unnamed: C2.1, U1.13 (AREF/PA0)
VCC: C1.1, C3.2, J3.3, J6.2 (VCC), JP2.1 (A), R2.2, U1.1 (VCC)
VDD: C4.1, J5.2, J8.1, JP3.2 (B)

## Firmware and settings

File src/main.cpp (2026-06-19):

/*
 * This file is part of the TinySensor distribution
 * (https://github.com/arcadien/TinySensor)
 *
 * Copyright (c) 2019 Aurelien Labrosse
 *
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
 * You should have received a copy of the GNU General Public License
 * along with this program. If not, see <http://www.gnu.org/licenses/\>.
 */

#include <config.h>
#include <conversionTools.h>

#if defined(USE_BH1750)
#include <BH1750.h>
#endif

#if defined(USE_DS18B20)
#include <Ds18b20.h>
#endif

#if defined(USE_LACROSSE)
#include <LacrosseWS7000.h>
#elif defined(USE_OREGON)
#include <Oregon_v3.h>
#endif

#if defined(__AVR_ATtiny84__)
#include <Attiny84aHal.h>
Attiny84aHal hal;
#else
#include <TestHal.h>
TestHal_ hal;
#endif

#if defined(USE_BME280) or defined(USE_BMP280)
#include <BMx280.h>
BMx280 bmx280(&hal);
#endif

#if defined(USE_DS18B20)
Ds18b20 ds18b20sensor(&hal);
#endif

#if defined(BATTERY_VOLTAGE_X10_ID) or defined(ANALOG1_X10_ID)
#include <x10rf.h>
x10rf x10encoder(&hal, 2);
#endif

#define NOT_SET (-1000.0f)
#define TRANSMIT_WITH_LED(code) \
  do {                          \
    hal.LedOn();                \
    code;                       \
    hal.LedOff();               \
    hal.Delay30ms();            \
  } while (0)

#if defined(USE_SERIAL_LOG)
#include <SoftSerial.h>
SoftSerial swSerial(&hal);

static void SerialPrintInfo(const char *name, uint16_t value,
                            const char *unit) {
  swSerial.print(name);
  swSerial.print(": ");
  swSerial.print(value);
  swSerial.print(unit);
  swSerial.println();
}
#else
static void SerialPrintInfo(const char *, uint16_t, const char *) {}
#endif

int main(void) {
  // Initialize hardware once at startup
  hal.Init();

  uint16_t batteryVoltageInMv = 0;
  bool lowBattery = false;

#if defined(USE_LACROSSE)
  LacrosseWS7000 environmentEncoder(&hal);
  environmentEncoder.SetAddress(LACROSSE_ID);
#elif defined(USE_OREGON)
  OregonV3 environmentEncoder(&hal);
  environmentEncoder.SetChannel(OREGON_CHANNEL);
  environmentEncoder.SetRollingCode(OREGON_RCODE);
#endif

  while (1) {
    hal.PowerOnSensors();

    float temperature = NOT_SET;
    float humidity = NOT_SET;
    float pressure = NOT_SET;

#if defined(USE_BME280) || defined(USE_BMP280)
    bmx280.Begin();
    hal.Delay30ms();
    temperature = bmx280.GetTemperature();
#if defined(USE_BME280)
    humidity = bmx280.GetHumidity();
    pressure = bmx280.GetPressure() / 100;
#endif
    bmx280.Shutdown();
#endif

#if defined(USE_DS18B20)
    ds18b20sensor.Convert();
    int16_t temp = ds18b20sensor.Read();
    if (temp != 0) {
      temperature = (float)temp;
    }
#endif

#if defined(BATTERY_VOLTAGE_X10_ID)
    uint16_t vccMv = hal.ComputeVccMv(INTERNAL_1v1);
#if defined(BATTERY_IS_VCC)
    batteryVoltageInMv = vccMv;
#else
    uint16_t rawBattery = hal.GetRawBattery();
    batteryVoltageInMv = hal.ConvertAnalogValueToMv(rawBattery, vccMv);
#endif
    lowBattery = (batteryVoltageInMv < LOW_BATTERY_VOLTAGE);
    SerialPrintInfo("Vbatt", batteryVoltageInMv, " mV");
    if (!lowBattery) {
      TRANSMIT_WITH_LED(
          x10encoder.RFXmeter(BATTERY_VOLTAGE_X10_ID, 0x00,
                              ConversionTools::dec16ToHex(batteryVoltageInMv)));
    }
#endif

#if defined(ANALOG1_X10_ID)
    if (!lowBattery) {
      uint16_t analogMeasurement = hal.GetRawAnalogSensor();
      SerialPrintInfo("Raw analog", analogMeasurement, " ADC");
      uint16_t analogVoltage =
          hal.ConvertAnalogValueToMv(analogMeasurement, vccMv);
      SerialPrintInfo("Analog voltage", analogVoltage, " mV");
      TRANSMIT_WITH_LED(x10encoder.RFXmeter(
          ANALOG1_X10_ID, 0x00, ConversionTools::dec16ToHex(analogVoltage)));
    }
#endif

#if defined(USE_BH1750)
    if (!lowBattery) {
      LacrosseWS7000 lightEncoder(&hal);
      lightEncoder.SetAddress(LACROSSE_ID);
      BH1750 lightMeter(0x23);
      lightMeter.begin(BH1750::ONE_TIME_HIGH_RES_MODE);
      _delay_ms(150);
      uint16_t lux = (uint16_t)lightMeter.readLightLevel();
      SerialPrintInfo("Luminosity", lux, " Lux");
      lightEncoder.SetLuminosity(lux);
      TRANSMIT_WITH_LED(lightEncoder.Send());
      TRANSMIT_WITH_LED(lightEncoder.Send());
    }
#endif

#if defined(USE_LACROSSE) or defined(USE_OREGON)
    if (temperature != NOT_SET) {
      environmentEncoder.SetTemperature(temperature);
    }
    if (humidity != NOT_SET) {
      environmentEncoder.SetHumidity(humidity);
    }
    if (pressure != NOT_SET) {
      environmentEncoder.SetPressure(pressure);
    }

#if defined(USE_SERIAL_LOG)
    SerialPrintInfo("Temp.", temperature * 10, " °C");
    SerialPrintInfo("RH ", humidity, " %");
    SerialPrintInfo("Pressure ", pressure, " hPA");
#endif

    if (temperature != NOT_SET) {
#if defined(USE_OREGON)
      environmentEncoder.SetBatteryLow(lowBattery);
#endif
      TRANSMIT_WITH_LED(environmentEncoder.Send());
    }
#endif

    hal.PowerOffSensors();
    hal.Hibernate((uint16_t)SLEEP_TIME_IN_SECONDS);
  }
}

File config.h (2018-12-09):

/*
 * config.h
 *
 * Created: 19/11/2018 22:14:40
 *  Author: aurelien
 */

#ifndef CONFIG_H_
#define CONFIG_H_

#include <inttypes.h>

// sleep 32s between each sample and
// emission
#define SLEEP_TIME_IN_SECONDS (8 * 4)

/*
 * 1-wire interface is on PA3
 * Power for radio is on PA2 (sensor_vcc)
 * LED pin is PB1
 * PWM pin is PA7
 * SDA pin is PA6
 * SCL pin is PA4
 * MISO pin is PA5
 * TX radio pin is PB0
 * BAT sensor pin is PA1
 * analog sensor pin is PA0
 */
#define LED_PIN PB1
#define PWM_PIN PA7
#define TX_RADIO_PIN PB0
#define RADIO_POWER_PIN PA2
#define BAT_SENSOR_PIN PA1

// Sensors
#define USE_BMP280
//#define USE_BME280
//#define USE_DS18B20 
// Protocols
#define USE_OREGON 1

// 0x5A, 0x5D pressure, temp, hygro
// 0xEA, 0x4C temp only
const uint8_t OREGON_TYPE[] = {0xEA, 0x4C};
const uint8_t OREGON_ID = 0xCB;

/*
 * MODE_0 0 // Temperature only [THN132N]
 * MODE_1 1 // Temperature + Humidity [THGR2228N]
 * MODE_2 2 // Temperature + Humidity + Baro() [BTHR918N]
 */
#define OREGON_MODE MODE_0

#endif /* CONFIG_H_ */

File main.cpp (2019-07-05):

/*
 * TinySensor.cpp
 *
 * Created: 02/10/2018 21:23:28
 * Author : aurelien
 */

/*
 * Puts MCU to sleep for specified number of seconds
 *
 * As the hardware watchdog is set for timeout after 8s,
 * the value used here will be divided by 8 (and rounded if needed).
 * It is better to use a multiple of 8 as value.
 */
void sleep(uint8_t s);

/*
 * Initial board setup
 *
 * This is where pins and various registers are set
 * for maximized power saving.
 */
void setup();

/*!
 * Entry point of the firmware.
 *
 * Will call setup, and enter in an infinite loop
 * where some code is executed, then the MCU is put
 * to deep sleep during a fixed number of seconds, then
 * the loop is processed again, aet-caetera.
 *
 */
int main(void);

/*
 * The firmware force emission of
 * a signal every quarter of an hour
 * even if sensor data does not change,
 * just to be sure sensor is not out of
 * power or bugged (900s)
 */
volatile uint16_t secondCounter;

/*!
 * Interrupt routine called each 8 seconds in the
 * default setup, which is the longest timeout period
 * accepted by the hardware watchdog
 */
volatile uint8_t sleep_interval;
ISR(WATCHDOG_vect) {
  wdt_reset();
  ++sleep_interval;
  // Re-enable WDT interrupt
  _WD_CONTROL_REG |= (1 << WDIE);
}

#if defined(USE_OREGON)
Oregon oregon;
#endif

#if defined(USE_bmX280) or defined(USE_BMP280)
BME280 bmX280;
#endif

void setup() {
  wdt_disable();

  secondCounter = 0;

  //
  //// Watchdog setup - 8s sleep time
  //
  _WD_CONTROL_REG |= (1 << WDCE) | (1 << WDE);
  _WD_CONTROL_REG = (1 << WDP3) | (1 << WDP0) | (1 << WDIE);

  //
  //// unused pins are input + pullup, as stated
  //// in Atmel's doc "AVR4013: picoPower Basics"
  //

  // all pins as input to avoid power draw
  DDRA = 0;
  DDRB = 0;

  // pull-up all unused pins by default
  //
  PORTA |= 0b01111001;
  PORTB |= 0b11111100;

  PRR &= ~_BV(PRTIM1);    // no timer1
  PRR &= ~_BV(PRADC);     // no adc
  ADCSRA &= ~(1 << ADEN); // p. 146

  ACSR |= (1 << ACD); // no analog comparator (p. 129)

  // deactivate brownout detection during sleep (p.36)
  MCUCR |= (1 << BODS) | (1 << BODSE);
  MCUCR |= (1 << BODS);
  MCUSR &= ~(1 << BODSE);

  // don't use ADC buffers (p. 131)
  DIDR0 |= (1 << ADC2D) | (1 << ADC1D);

  // set output pins
  DDRB |= _BV(TX_RADIO_PIN);
  DDRA |= _BV(RADIO_POWER_PIN);
  DDRB |= _BV(LED_PIN);
}

int main(void) {

  setup();

#if defined(USE_OREGON)
  oregon.setType(oregon._oregonMessageBuffer, OREGON_TYPE);
  oregon.setChannel(oregon._oregonMessageBuffer, Oregon::Channel::ONE);
  oregon.setId(oregon._oregonMessageBuffer, OREGON_ID);
#endif

#if defined(USE_bmX280) || defined(USE_BMP280)
  bmX280.setI2CAddress(0x76);
  bmX280.beginI2C();
  bmX280.setStandbyTime(5);
#endif

#if defined(USE_OREGON)
// Buffer for Oregon message
#if OREGON_MODE == MODE_0
  uint8_t _lastOregonMessageBuffer[8] = {};
#elif OREGON_MODE == MODE_1
  uint8_t _lastOregonMessageBuffer[9] = {};
#elif OREGON_MODE == MODE_2
  uint8_t _lastOregonMessageBuffer[11] = {};
#else
#error mode unknown
#endif
#endif

  while (1) {

#if defined(USE_OREGON) && (defined(USE_bmX280) || defined(USE_BMP280))
    Wire.begin();

    oregon.setBatteryLevel(oregon._oregonMessageBuffer, 1);
    oregon.setTemperature(oregon._oregonMessageBuffer, bmX280.readTempC());

#if defined(USE_bmX280)

    oregon.setHumidity(oregon._oregonMessageBuffer, bmX280.readFloatHumidity());
    oregon.setPressure(oregon._oregonMessageBuffer,
                       (bmX280.readFloatPressure() / 100));
#endif
    oregon.calculateAndSetChecksum(oregon._oregonMessageBuffer);

    Wire.end();
#endif

#if defined(USE_DS18B20)

    ds18b20convert(&PORTA, &DDRA, &PINA, (1 << 3), nullptr);

    // Delay (sensor needs time to perform conversion)
    _delay_ms(1000);

    // Read temperature (without ROM matching)
    int16_t temperature = 0;
    ds18b20read(&PORTA, &DDRA, &PINA, (1 << 3), nullptr, &temperature);

    oregon.setBatteryLevel(oregon._oregonMessageBuffer, 1);
    oregon.setTemperature(oregon._oregonMessageBuffer, temperature / 16);
    oregon.calculateAndSetChecksum(oregon._oregonMessageBuffer);

#endif

    bool shouldEmitData = false;
#if defined(USE_OREGON)

#if (OREGON_MODE == MODE_0)
    // temp update?
    shouldEmitData =
        (oregon._oregonMessageBuffer[4] != _lastOregonMessageBuffer[4] ||
         oregon._oregonMessageBuffer[5] != _lastOregonMessageBuffer[5] ||
         oregon._oregonMessageBuffer[6] != _lastOregonMessageBuffer[6]);

#elif (OREGON_MODE == MODE_1)
    // temp or humidity update?
    shouldEmitData =
        (oregon._oregonMessageBuffer[4] != _lastOregonMessageBuffer[4] ||
         oregon._oregonMessageBuffer[5] != _lastOregonMessageBuffer[5] ||
         oregon._oregonMessageBuffer[6] != _lastOregonMessageBuffer[6] ||
         oregon._oregonMessageBuffer[7] != _lastOregonMessageBuffer[7]);
#elif (OREGON_MODE == MODE_2)
    // temp, humidity or pressure update?
    shouldEmitData =
        (oregon._oregonMessageBuffer[4] != _lastOregonMessageBuffer[4] ||
         oregon._oregonMessageBuffer[5] != _lastOregonMessageBuffer[5] ||
         oregon._oregonMessageBuffer[6] != _lastOregonMessageBuffer[6] ||
         oregon._oregonMessageBuffer[7] != _lastOregonMessageBuffer[7] ||
         oregon._oregonMessageBuffer[8] != _lastOregonMessageBuffer[8] ||
         oregon._oregonMessageBuffer[9] != _lastOregonMessageBuffer[9]);
#else
#error OREGON_MODE has an unknown value
#endif

    // absolute counter for emission ~ each 15 minutes
    if (secondCounter > 900) {
      secondCounter = 0;
      shouldEmitData = true;
    }

    PORTB |= _BV(LED_PIN); // led on

    if (shouldEmitData) {

      // Activate radio power
      PORTA |= _BV(RADIO_POWER_PIN);
      _delay_ms(2);

      // led off here, it will allow a short
      // blink when actually emitting new data
      PORTB &= ~_BV(LED_PIN);

// Buffer for Oregon message
#if OREGON_MODE == MODE_0
      memcpy(_lastOregonMessageBuffer, oregon._oregonMessageBuffer, 8);
#elif OREGON_MODE == MODE_1
      memcpy(_lastOregonMessageBuffer, oregon._oregonMessageBuffer, 9);
#elif OREGON_MODE == MODE_2
      memcpy(_lastOregonMessageBuffer, oregon._oregonMessageBuffer, 11);
#else
#error mode unknown
#endif

      oregon.txPinLow();
      _delay_us(oregon.TWOTIME * 8);

      oregon.sendOregon(oregon._oregonMessageBuffer,
                        sizeof(oregon._oregonMessageBuffer));

      // pause before new transmission
      oregon.txPinLow();
      _delay_us(oregon.TWOTIME * 8);

      // second emission with led on
      PORTB |= _BV(LED_PIN);

      oregon.sendOregon(oregon._oregonMessageBuffer,
                        sizeof(oregon._oregonMessageBuffer));

      // radio off
      PORTA &= ~_BV(RADIO_POWER_PIN);
    }
    // led off
    PORTB &= ~_BV(LED_PIN);

#endif
    sleep(SLEEP_TIME_IN_SECONDS);
    secondCounter += SLEEP_TIME_IN_SECONDS;
  }
}
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

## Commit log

2018-10-20 Fixes about AVR4013 Atmel notes
    [main.cpp]
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2018-10-22 Updated card layout
    * Use new ICSP footprint
    * Better capacitor footprint
    * board limits
    * removed all tracks, to be refined
    [tinySensorv1.kicad_pcb, tinySensorv1.sch]
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2018-11-11 Avoid acid trap in traces (PCB)
    [tinySensorv1.kicad_pcb]
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2018-11-14 Fix HW bugs around analog sensor and begin radio connector move
    [tinySensorv1.kicad_pcb, tinySensorv1.sch]
2018-11-18 Use new DCDC converter footprint, do no explicitely display GND
    [tinySensorv1.kicad_pcb, tinySensorv1.sch]
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2018-11-25 Update for a DS18B20 node
    * Fixed Oregon setup with new hardware (pin setup)
    * Added a config.h file for all #defines and setup
    * Added library as external module for Dallas DS18B20
    [Oregon.cpp, config.h, main.cpp]
2018-12-04 Fix a copy/paste typo error
    [main.cpp]
2018-12-04 Add minimal emission interval
    * Added a counter so that an emission is made every 15 minutes (approx)
    to detect failure of the sensor.
    * Added comments
    [main.cpp]
2018-12-09 Fix bug in LED pin
    [config.h]
2019-07-05 fix(ds18b20): use fork for DS18B20 sensor
2019-07-09 chore(structuration): big enhancement for build
    * Add CMake support for non-Atmel studio environments
    * Allow build with AVR toolchain
    * Introduce unit testing using Unity project
    * Fixed 'hardcoded' setup for Atmel Studio
    [config.h, main.cpp]
2019-07-10 Fix useless call on Wire library
    [main.cpp]
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2019-07-10 fix(tiny-i2c): Slight fixes to make it work
    [main.cpp]
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2020-01-07 Fix constant name for BME280 sensor
    [main.cpp]
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2020-01-20 lint: Fix copyright headers
    [Arduino.h, Oregon.cpp, config.h]
2020-01-20 fix: Dev module now uses BMP280 only
    [config.h, main.cpp]
2020-02-11 feat: Use PlatformIO in CI
    * Use only one build system: PlatformIO. It can now replace CMake.
    [config.h]
2020-06-26 chore(error mangement): Account read error from DS18B20 library
    [main.cpp]
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2020-06-28 feat: Many updates of PCB
    * Fixed many polarity bugs: Vcc is always on the square pad, but
    for 433Mhz emmiter which is somewhat strange
    * Added INT0 header
    * Allow resistor bridge on analog sensor, to allow usage of LDR
    [tinySensorv1.kicad_pcb, tinySensorv1.sch]
2020-10-31 feat(board): Allow sub-Vss analog ref for analog sensor
    [tinySensorv1.kicad_pcb, tinySensorv1.sch]
2020-10-31 Fix: change AA battery footprint
    [tinySensorv1.kicad_pcb]
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2020-10-31 Fix: better labelling
    [tinySensorv1.kicad_pcb]
2020-10-31 chore: Fix DS18B20 library inclusion
    [main.cpp]
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2020-10-31 fix: SENSOR_VCC must be up to setup I2C sensors
    [main.cpp]
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2020-11-02 fix: label too close to a copper element
    [tinySensorv1.kicad_pcb]
2020-11-02 fix: missing connections in analog
    [tinySensorv1.kicad_pcb]
2020-11-02 fix: analog (LM35) documentation and layout
    [tinySensorv1.kicad_pcb, tinySensorv1.sch]
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2023-01-18 fix: bad cast truncating sleep duration
    [main.cpp]
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2023-01-18 optim: Rework on sleep function
    [main.cpp]
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2023-01-18 fix: Added missing variable initialization
    [main.cpp]
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2023-01-22 Fix ADC frequency and lower sample count
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2023-08-03 chore: Fix PlatformIO devices configs
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2023-08-03 WIP : new file, fixed battery, added multi checksum
2023-08-03 fix: battery level is at byte 4 not 3
2023-08-03 fix: better setup for ADC
2023-08-04 Cleanup and fix HAL API
    [config.h, main.cpp]
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2023-08-04 Fix voltage readings
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2023-08-04 Fix tests after refacto
    [bussesTest.cpp]
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2023-08-05 Fix sensor ID computation
2023-08-05 Fix: encoding of low battery
2023-08-05 fix: low battery encoding
2023-08-05 fix: temperature encoding
2023-08-05 fix: negative temperature encoding
2023-08-05 fix: good battery level encoding
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2023-08-06 fix: Use Oregon channel from -D definition
    [main.cpp]
2023-08-06 fix: Battery ok flag is 0, not 1
2023-08-12 fix: pressure encoding
2023-08-26 fix: battery status API
2023-08-28 fix: battery failure status clear
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2023-09-04 fix: add 400µs delay and small changes
    * InitI2C() become Init()
    [bussesTest.cpp]
2023-09-11 Fix: Filtering does not manage exclusion correctly
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2023-09-11 chore: Fix voltage readings
    [main.cpp]
2023-09-11 fix: Only send battery voltage each 900 seconds
    [main.cpp]
2023-09-12 fix: Sleep duration in sec can be more than 255
    [main.cpp]
2023-09-12 fix: Only send voltage if voltage sensor ID is defined
    [main.cpp]
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2023-09-12 test: add testcase for X10 Sensor (missing pressure)
    [x10LibTest.cpp]
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2023-09-13 fix: Battery reading
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2023-09-20 chore: rename software serial to avoid clash with Arduino
2023-09-20 chore: avoid double define of USE_I2C
    [config.h]
2023-09-20 fix: Better ADC usage
    [main.cpp]
2023-09-20 chore: ongoing rework on serial logging
    [main.cpp]
2023-09-24 fix: compilation in cross environment
    [bussesTest.cpp]
2023-09-24 chore: avoid compiler warnings
    [main.cpp]
2023-10-01 fix: prevent BMx280 query before measurement
    [main.cpp]
2023-12-05 fix: make secondary analog measurement more generic in source code
    [main.cpp]
2025-12-20 Comprehensive power and flash optimization for ATtiny84A
    Power Optimizations:
    - src/main.cpp: Implement battery-aware operation
    * Add lowBattery flag tracking (initialized at startup, outside loop)
    * Skip BATTERY, ANALOG, and LIGHT sensor transmits when battery critical
    * Reduce environment encoder transmit from 2x to 1x when low battery
    * Replace BMx280 busy-wait with fixed Delay30ms() to save CPU active time
    * Move encoder initialization outside main loop to eliminate redundant setup
    Hardware Abstraction Layer:
    - lib/hal/Attiny84aHal.cpp: Optimize ADC power consumption
    * Reduce ADC sampling from 24 total samples (8 ignored + 16 counted) to 10 (2 ignored + 8 counted)
    * Result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
    [main.cpp]
2026-06-16 fix: correct inverted PRR bit direction in UseLessPowerAsPossible
    PRR bits set to 1 power DOWN a peripheral; &= ~_BV() was clearing
    the bits (leaving Timer1 and ADC powered on). Both lines corrected
    to |= to actually reduce consumption during idle.
2026-06-16 fix: guard SetChannel against out-of-range values
    Oregon protocol channels are 1-3; values outside this range shift
    bits into the sensor ID nibbles, corrupting message[2]. Guard added.
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2026-06-18 chore: remove dead code and stale artifacts (C3, C11, D5, I3)
    C3: drop orphan free function Init() in Attiny84aHal.cpp — never
    called, shadowed Attiny84aHal::Init silently.
    C11: drop dead clamp `if (pressure < 200) pressure = 200` in
    LacrosseWS7000::SetPressure — immediately overwritten by the < 850
    clamp below it.
    D5: git rm avrdude.conf (534 KB) — belongs to PlatformIO toolchain,
    not the source tree.
    I3 (audit-revisited): KiCAD backup ZIP was never tracked by git;
    *.zip already covered by .gitignore — non-issue like I1.
    All 51 native tests pass.
2026-06-18 fix(tooling): portable scripts and pinned PlatformIO deps (I2, D3, D4)
    I2: Makefile now uses PIO ?= $(HOME)/.platformio/penv/bin/pio and
    TARGET ?= S_03 (overridable); cp replaces Windows-only copy.
    scripts/flash_tinySensor uses PIO_HOME and PROJECT_DIR env vars with
    portable defaults — no more hardcoded /var/services/homes/aurelien paths.
    D3+D4: pin all five PlatformIO lib_deps to their current HEAD SHA
    instead of floating branch names. Reproducible builds, no silent
    breakage on upstream force-push or branch deletion.
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2026-06-19 arch(TECH-HAL-001): fix V2/V3/V4 architectural violations
    V2: remove dead #include <AnalogFilter.h> from Attiny84aHal.cpp —
    the header was included but AnalogFilter is never referenced; AdcRead
    uses local variables for warmup/accumulation.
    V3/V4: declare ds18b20 and BH1750 as explicit components in
    docs/architecture.md diagram and component-responsibilities table.
    These sensor drivers were used in main.cpp but absent from the
    declared architecture.
2026-06-19 test(TECH-X10-001,TECH-X10-002): add HAL timing token and x10rf delegation tests
    Adds 14 integration tests covering:
    - TECH-X10-001: TestHal_ must append a distinct single-character token for
    each of the five new X10 timing methods (PreambleHigh='Q', PreambleLow='R',
    BitShort='T', BitLong='U', Gap='G'); tokens must not collide with existing ones.
    - TECH-X10-002: x10rf::SendCommand and SendX10RfBit must route all timing
    through the Hal interface; preamble ordering, per-repeat gap count, and
    bit-type (short vs long) are all verified via the Orders token stream.
    [x10HalTimingTest.cpp]
2026-06-19 tech(TECH-X10-002): route x10rf timing through Hal; remove direct _delay_us calls
    Replace the hard-coded _delay_us / #define constants in x10rf.cpp with
    calls to hal->DelayX10PreambleHigh(), hal->DelayX10PreambleLow(),
    hal->DelayX10BitShort(), hal->DelayX10BitLong(), and hal->DelayX10Gap().
    Also relocate x10HalTimingTest.cpp to its own test_x10_hal suite so it
    compiles in an isolated unit with the full updated TestHal_ stub.
    [x10HalTimingTest.cpp]
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2026-10-26 tech(TECH-SERIAL-001): drive SoftSerial through HAL SerialWriteBit
    Audit C6 + T4. SoftSerial called _delay_us() directly, which broke the
    HAL contract and made it impossible to build or test natively.
    - Hal: SerialGoHigh/SerialGoLow replaced by SerialWriteBit(level), which
    sets the line and holds it one bit period. One virtual call per bit as
    before, so the AVR bit timing is preserved (callee gains one branch,
    caller loses one: within 1-2 cycles; 40 bytes of flash saved).
    - Attiny84aHal owns the bit period (SERIAL_BIT_PERIOD_US, unchanged).
    - TestHal records 'S'/'W' per bit (same tokens as before).
    - New native suite test_softSerial (frame layout, strings, numbers,
    radix, println).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
2026-10-26 hw: OpenSCAD enclosure and outdoor sensor shield in openscad/
    - tinysensor_box.scad: wall-mounted box for PCB v2.2, screwed lid with
    gasket groove, int (vents) / ext (PG7 gland) variants
    - sensor_shield.scad: stacked-plate radiation shield for BMx280
    breakout, wall bracket or snap clip under the main box
    - assembly.scad + rendu.png: overview render
    - README.md: export commands, assembly, hardware list, open points
    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
2026-10-26 hw: side cable gland, table stand, smaller sensor shield, open-box render
    - tinysensor_box.scad: PG7 gland moved to the side wall by default
    (gland_side = left/right/bottom), under the flange chamfer; new
    part="open" render with the board inside and the lid flipped beside
    - stand.scad: table stand (mast screwed on the box wall ears + foot with
    socket) to stand box + clipped shield upright
    - sensor_shield.scad: shield shrunk from D80 x 72 to D56 x 52 mm
    (column 26, pitch 10, skirt 5); assembly/stand realigned
    - pcb.scad: simplified v2.2 board + 18650 from the KiCad positions
    - euro2.scad: 2-euro coin for scale in all renders
    - renders: rendu.png, rendu_pied.png, rendu_ouvert.png; READ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
2026-10-26 hw: mushroom v2 — one-piece cap on a tilted stem, lobed outline, tip
    - cap = dome + gill disc, set on the stem at 10° (tilted tenon in a
    collar); all electronics in the cap: chassis printed upright with the
    BME280 lying flat over the gill slots, perforated deck, cropped board,
    charger upright with micro-USB facing down between two gills; the stem
    only holds the 18650
    - outline generator (lobe_seed/n/amp/top/rot): random harmonics, full at
    the rim and fading to the top, flat rim; clearance index echoed so any
    seed is checked against the electronics; dome tabs follow the lobes
    - tip: smooth (1-d²)³ bump on top of the dome, gentle on one side and
    steeper on the other, zero at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
2026-10-27 hw: mushroom — BME280 plugged under the PCB, no sensor wires
    The breakout's male header goes straight into a 6-position female 2.54
    header soldered under the board in the I2C footprint (5 NC = CSB, 6 GND
    = SDO -> 0x76). BME rails removed, deck opening for the header, three
    more vent slots near the sensor, part="sensor" close-up view.
    pcb.scad: jst_eh option (I2C / I2C_SPI JSTs not fitted in the mushroom).
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2026-11-02 hw: mushroom gourd cap from sketch, foot shortened 30 mm
    Cap follows a meridian profile (lower bulb, waist, top bulb centred on
    J1) instead of superellipse + tip; 45° inner ceiling so the top needs no
    supports behind the narrow neck. stem_h 125 -> 95, ballast_h 40 -> 12,
    tilt 10° -> 6°. export.sh uses the OpenSCAD AppImage from ~/bin.
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2026-11-02 docs: mushroom top offset, antenna path, stability estimate, harness text
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2026-11-02 hw: mushroom electronics 20 mm higher again, slanted top vent
    chamber_h 48, ballast_h 52 (~343 g). Chassis windows moved up beside the
    BME280. Ø5 vent from the ceiling tip down to the rear flank: rain stays
    out and it does not sit over J1. Limit: +30 mm breaks 3 mm clearance.
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2026-11-02 hw: mushroom USB back under the cap, foot bulge dropped
    Reverts cc14016, 613dffb, a56efc3 and 3cc6374: the bulge was ugly, the
    charger socket goes back through the disc.
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2026-11-06 hw: one Orca project per model, box, shield and stand join the mushroom
    update_3mf.py handles every project in print/: updates meshes in place
    (plates, positions, settings kept) and creates a missing project with one
    plate per use, printer and filament settings from mushroom.3mf. The nine
    separate box, shield and stand 3MF are removed; export.sh runs the script.
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2026-11-06 fix(PLAT-POWER-003): hold sensor rail and radio data low in sleep, no pull-up into the sensor rail
2026-11-06 hw: rework guide, TPS63020 buck-boost wired in place of the J2 module
2026-11-06 hw: PCB v3.0 from the review (D1, PA1 divider, Q1 reverse protection, GND island, SDO selector, cut-line keep-outs)
    Built by scripts/make_v3_pcb.py from the v2.2 board (KiCad 10 pcbnew).
    DRC: 0 unconnected, no clearance/short errors; schematic parity
    pending until the schematic is updated to v3.0.
2026-11-06 hw: schematic v3.0 in sync with the PCB (rev 3.0)
    Schematic (KiCad 10 format): D1 turned, PA1 on BAT_SENSE with R7/R8/C7,
    battery block redrawn with Q1 AO3401A on RAW IN / BT1 18650, J11/J12
    removed, J3 + J14 sensor connectors with JP6 SDO selector, C8 radio
    decoupling, R9 RESET pull-up, C5/C6 footprints, 2.7 mm holes.
    PCB footprints linked to the symbols and pad nets taken from the netlist.
    Orphan footprints (J13 terminal, 18650 holder) moved to the project
    library, dead library entries removed.
    DRC with schematic parity: 0 footprint errors, 0 unconnected pads,
    only J10's malformed courtyard (library footprint) left as error.
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2026-11-07 arch(CONF-BUILD-004): trace the LACROSSE_ID #error to config.h
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2026-11-08 hw: print mushroom gills flipped by rotation, not mirror
    mirror([0,0,1]) gave a left-handed disc that could not fit the lobed cap.
    rotate([180,0,0]) flips it upside down and keeps its handedness. 3MF
    regenerated.
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2026-11-09 feat(FUNC-DECODE-002): LacrosseDecoder rebuilds WS7000 frames from pulses
    Sync of at least 6 zero bits, LSB-first nibbles with 1 separators, frame
    length from the type nibble, XOR and sum checks; a failing pulse is
    re-checked as a sync high.
    Also covers FUNC-DECODE-003: measurements exposed as integer tenths
    (temperature, humidity, pressure) and lux, 0 when the type lacks them.
    Requirements: FUNC-DECODE-002, FUNC-DECODE-003
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2026-11-09 test(FUNC-DECODE-006): SourceTable loopback mapping per encoder, in-place update, distinct kinds, oldest replaced when full
2026-11-09 feat(FUNC-DECODE-006): SourceTable keeps the last record of each radio source
    Maps Oregon, Lacrosse and X10 decoder output to a common SourceRecord
    (tenths, lux, mV from X10 BCD), updates known sources in place, appends
    new ones and replaces the least recently seen when the 6 slots are full.
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2026-11-09 ui(UI-DECODE-001): FormatPage renders a source record as two 16-character lines
    Line 1: temperature, humidity, lux, volts then the right-aligned source
    label; line 2: pressure then the right-aligned age (s/m/h/d, capped 99d).
    Fixed buffers only, no printf.
2026-11-09 arch(UI-DECODE-002): add Font8x16 to tinyDecoders, fix SourceTable capacity to 6
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2026-11-09 tech(PLAT-DECODE-001): Attiny84aReceiverHal captures pulses on ICP1 with Timer1 at 1 us
    Init makes PA7 an input without pull-up and runs Timer1 at 8 MHz / 8 with
    the noise canceller, first edge opposite to the current level. TIM1_CAPT
    toggles ICES1 and pushes the ended pulse (low if the edge rose), clamped to
    65535 after a full timer period, into a 32-pulse ring buffer dropping when
    full. TIM1_OVF adds 65536 us and counts seconds. PopPulse and NowSeconds
    read inside ATOMIC_BLOCK.
2026-11-09 tech(PLAT-DECODE-002): Attiny84aReceiverHal drives the SSD1306 128x32 over TinyI2C
    Init sends the fixed SSD1306 sequence at 0x3C (USI: SDA PA6, SCL PA4), from
    PROGMEM, clears the 4 pages x 128 columns, then turns the display on.
    DrawChar reads the glyph with ReadGlyph and writes its two halves to pages
    2*row and 2*row+1 at column col*8. No framebuffer in RAM.
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2026-11-09 conf(CONF-DECODE-001): attiny84a env builds the receiver firmware within 8 KB / 384 B
    [env:attiny84a]: ATtiny84A at 8 MHz internal RC (lfuse 0xE2), no framework,
    pinned tinyi2c, root upload settings, 8192 B flash and 384 B RAM limits.
    scripts/check_size.py runs avr-size after the link and fails the build when
    .data + .bss exceed maximum_ram_size, since PlatformIO only warns.
    include/Arduino.h gives TinyI2C the ATtiny84 USI pin macros. main.cpp keeps
    hal and receiver at file scope so the check counts them.
    Measured: flash 6314 / 8192 B, static RAM 323 / 384 B.
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2026-11-10 hw: mushroom 3MF regenerated with the stem and gills for the USB clearance
    Orca plates and per-object settings (wood PLA gills) kept.
2026-11-10 hw: sink mushroom cradle stop plates 1 mm deeper
    Measured on the print: the plates sat 1 mm too high in their slots.
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2026-11-10 hw: mushroom cradle tabs up, wire notches, looser fit
    From the first print: the stop plates go in tab up, with the wire
    soldered on top. The bottom tab slots are gone. Each end gets a notch
    next to the tab so the wire runs along the cell in the open top.
    Radial fit goes from 0.4 to 0.8 mm. The slots sink 1.5 mm (1 mm
    measured, +0.4 for the smaller radius). Adds a cradle_view render part.
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2026-11-11 tech(PLAT-DECODE-003): ProMicroReceiverHal captures pulses on ICP1 PD4 with Timer1
    PD4 input without pull-up; Timer1 fully reconfigured: normal mode,
    prescaler 8 (0.5 us), noise canceller, edge toggled per capture. Durations
    are ticks / 2, 65535 after a full period, into a 64-pulse ring dropped when
    full; overflows add 32768 us to the seconds clock. Atomic reads.
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2026-11-11 test(FUNC-DECODE-004): OregonDecoder on the Oregon v2.1 layout and RFLink windows
    Loopback of the three FUNC-OREGON-014 devices, the four RFLink captures
    (Plugin_048.c lines 644-645, 685-686), a 0x1A3D copy, battery flags bits 2-3,
    window bounds 149/150, 599/600, 1199/1200 us, 11 vs 12 sync ones, flipped
    data bits and unknown IDs (old 0xEC40 layout included) rejected.
    Also FUNC-DECODE-005: measurements of the loopback frames and captures
    (215; 196; 215/67; 205/78), pressure b8 + 795 with the bench vector
    0xB4 -> 975 hPa.
    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
2026-11-11 test(FUNC-DECODE-006): Oregon sources keyed by channel and rolling code, capacity 8
    SourceRecord gains `code` (rolling code for Oregon, 0 otherwise); two Oregon
    frames on channel 2 with codes 0xB8 and 0x36 give two records; native
    capacity is 8 and a 9th source replaces the least recently seen one.
    Oregon mapping cases use the FUNC-OREGON-014 devices (THGR228N, BTHR918).
    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
2026-11-11 feat(FUNC-DECODE-004): OregonDecoder on the Oregon v2.1 layout and RFLink windows
    Short 150-599 us, long 600-1199 us; at least 12 sync ones, b0 starts at
    the first zero (sync nibble 0xA); IDs EA4C (60 bits), 1A2D/1A3D (72),
    5A5D (88), checksum at nibbles 13/16/20. Rolling code is b3, battery low
    (b4 & 0x0C), temperature from b4/b5 with sign bit 3 of b6, humidity
    (b7 & 0x0F)*10 + (b6 >> 4), pressure b8 + 795.
    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
2026-11-11 feat(FUNC-OREGON-015): OregonV3 setters replace their field on a reused instance
    SetChannel replaces the channel nibble, SetTemperature clears the previous
    sign and assigns the temperature nibbles, THN132N checksum nibble is
    rewritten instead of OR-ed.
    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
2026-11-12 tech(TECH-DECODE-002): shared AtmegaReceiverHal for Pro Mini and Pro Micro, ATtiny receiver dropped
    ProMicroReceiverHal becomes AtmegaReceiverHal, compiled on ATmega328P and
    ATmega32U4; only the ICP1 pin differs (PB0/D8 or PD4). ReceiverHal.h aliases
    it on both MCUs, TestReceiverHal on native, #error otherwise. The ATtiny84a
    receiver (HAL, entry point, env, TinyI2C dep, Arduino.h shim, check_size.py)
    is removed; main_promicro.cpp becomes the single src/main.cpp.
    Requirements: TECH-DECODE-002, PLAT-DECODE-003, PLAT-DECODE-004, PLAT-DECODE-005
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2026-11-12 req(FUNC-DECODE-004): Oregon short/long threshold at 732 µs (half-bit/bit midpoint)
    A weak THGN132N on the RXB6 gives short lows up to 649 µs; the RFLink
    600 µs threshold dropped most of its frames.
2026-11-12 arch(FUNC-DECODE-004): OregonDecoder windows short 150–731, long 732–1199 µs
2026-11-12 test(FUNC-DECODE-004): Oregon windows short 150-731, long 732-1199 us; asymmetric weak-sensor frame decodes
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2026-11-13 hw: receiver Pro Micro on pin rails, RXB6 flipped on its shield
    Drop the Pro Mini and the USB-serial module: the Pro Micro stands on its
    8 mm header pins in two drilled rails (removable for breadboard use), its
    micro-USB at the rear opening. The RXB6 lies across, components down, its
    shield resting on two supports beside the Pro Micro with end ergots (plus
    glue); pin stubs face up for wires and decoupling caps. Measured RXB6,
    quartz, shield, OLED (active-area offsets from the maker drawing), Pro
    Micro and helical antenna dimensions; asserts guard pin depth, shield
    bite, antenna headroom.
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2026-11-13 hw: receiver screw bosses rise to the walls at 45deg, bottom plate recessed flush
    Bosses no longer start in mid-air when the shell prints upside down: each
    one hulls up to its inner wall corner at 45deg. The shell walls go down by
    plate_t and the plate fits inside them (0.2 mm clearance), flush with the
    shell bottom.
2026-11-13 hw: receiver M3x6 machine screws, cylinder heads recessed in plate pads
    Measured screw head 5.4 x 3.1 mm: counterbored 3.3 mm from below into a
    2.5 mm pad under each boss, 1.2 mm floor under the head. Bosses start on
    the pads; pilot 2.5 mm (drill 2.8 if the screw binds) ends 0.5 mm past an
    M3x6 tip. M3x8 would need taller bosses that reach the OLED.
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2026-11-13 hw: receiver shell rounded on every edge, walls 2 mm all round
    body() is now a minkowski of the inset convex profile with a sphere, so
    the side edges get the same 2 mm radius as the front ones. It also fixes
    the inner offset: the old 2D offsets inset the front, rear and top walls
    by 3.5 mm instead of 2, which ate the headroom over the antenna and the
    room for the Pro Micro USB plug at the rear.
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2026-11-13 hw: receiver screw bosses moved inward, plate pads whole
    The plate pads were clipped by the walls; bosses now sit pad_d/2 + clearance
    inside the walls so each pad is a full ring around the counterbore. Shell
    bosses and their 45deg gussets follow.
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2026-11-13 docs: hardware and debugging docs in English
    REWORK_v2.2, VARIANTE_LM35 (file name kept: code, requirements and
    CLAUDE.md point to it), BACKLOG, the 2026-11-06 PCB review header and
    docs/debugging.md translated from French.
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

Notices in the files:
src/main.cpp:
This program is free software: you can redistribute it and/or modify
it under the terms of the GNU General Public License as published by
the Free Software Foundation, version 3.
